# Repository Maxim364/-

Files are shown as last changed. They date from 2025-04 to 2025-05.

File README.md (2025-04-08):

# Электронно-механические часы на ПЛИС

## Описание проекта

Данный проект представляет собой курсовую работу, посвящённую разработке электронно-механических часов на базе программируемой логической интегральной схемы (ПЛИС) с использованием встроенного процессора (HPS). В рамках проекта реализована система, получающая текущее время из операционной системы Linux, работающей на HPS, и передающая его в ПЛИС для аппаратного отображения. Также предусмотрено управление подсветкой часов с помощью Python-программы.

Проект объединяет аппаратную и программную части, а также 3D-моделирование.

## Состав репозитория

Репозиторий содержит следующие основные компоненты:

### 1. **Проект Quartus**
Каталог `quartus_project/` содержит файлы проекта Quartus Prime, включая:

- HDL-файлы, реализующие логику отображения времени;
- Проект Qsys с настройкой взаимодействия между HPS и FPGA;
- Конфигурационные файлы (`.qsf`, `.qpf`, `.sdc`) проекта Quartus.

### 2. **Программа для HPS**
Каталог `hps_program/` содержит C-программу, выполняемую на процессоре HPS:

- Получение текущего времени из Linux и передача его в FPGA посредством C-программы;
- Makefile для сборки программы под ARM-платформу.
- Скомпилированная C-программа.

### 3. **3D-модель часов**
Каталог `models/` включает файлы для реализации 3D-модели часов:

- 3D-модели каждого элемента часов.
- Сборка модели.
- STL файлы для печати на 3D-принтере.

### 4. **Скрипт управления подсветкой**
Каталог `python_tools/` содержит Python-скрипт, управляющий подсветкой устройства:

- `backlight_control.py` — позволяет переключать режимы подсветки;

### 5. **Документация**
Каталог `doc/` содержит материалы курсовой работы:

- Отчет;
- Руководство разработчика;
- Руководство пользователя.

### 6. **Образ Linux**
Каталог `linux_image/` содержит необходимые файлы для запуска Linux на HPS:

- Предсобранный образ Linux (`Image`);
- Инструкции по прошивке на SD-карту;

## Назначение проекта

Проект направлен на интеграцию программируемой логики с системой на базе Linux, развитие навыков работы с ПЛИС и системным программированием, а также демонстрацию взаимодействия аппаратных и программных средств в рамках одной функциональной системы.

---

**Авторы:** *Батаев Максим, Леснов Илья*  
**Проект выполнен в рамках курсовой работы по дисциплине "Алгоритмизация и программирование"*

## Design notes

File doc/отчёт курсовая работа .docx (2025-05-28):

ФЕДЕРАЛЬНОЕ ГОСУДАРСТВЕННОЕ АВТОНОМНОЕ ОБРАЗОВАТЕЛЬНОЕ УЧРЕЖДЕНИЕ ВЫСШЕГО ОБРАЗОВАНИЯ

«НАЦИОНАЛЬНЫЙ ИССЛЕДОВАТЕЛЬСКИЙ УНИВЕРСИТЕТ

«ВЫСШАЯ ШКОЛА ЭКОНОМИКИ»

###### МОСКОВСКИЙ ИНСТИТУТ ЭЛЕКТРОНИКИ И МАТЕМАТИКИ

###### им. А.Н. ТИХОНОВА

Леснов Илья Андреевич, группа БИВ248

Батаев Максим Алексеевич, группа БИВ248

ЭЛЕКТРОННО-МЕХАНИЧЕСКИЕ ЧАСЫ НА ПЛИС

Курсовая работа

по направлению 09.03.01 Информатика и вычислительная техника

студентов образовательной программы бакалавриата
«Информатика и вычислительная техника»

Студент ___________________ _________________

подпись И.О. Фамилия

Студент ___________________ _________________

подпись И.О. Фамилия

Рецензент ученая степень, звание (при наличии) ___________________ И.О. Фамилия | Руководитель ученая степень, звание (при наличии) ____________________ И.О. Фамилия Консультант ученая степень, звание (при наличии) ____________________ И.О. Фамилия

ЗАДАНИЕ НА КР

ФЕДЕРАЛЬНОЕ ГОСУДАРСТВЕННОЕ АВТОНОМНОЕ ОБРАЗОВАТЕЛЬНОЕ УЧРЕЖДЕНИЕ ВЫСШЕГО ОБРАЗОВАНИЯ

«НАЦИОНАЛЬНЫЙ ИССЛЕДОВАТЕЛЬСКИЙ УНИВЕРСИТЕТ

«ВЫСШАЯ ШКОЛА ЭКОНОМИКИ»

###### МОСКОВСКИЙ ИНСТИТУТ ЭЛЕКТРОНИКИ И МАТЕМАТИКИ

ЗАДАНИЕ

на курсовую работу бакалавра

студенту группы БИВ248 Леснову Илье Андреевичу

1. Тема работы

Электронно-механические часы на ПЛИС

Electronic-mechanical clock on FPGA

2. Требования к работе

Разработать Электронно-Механические часы на ПЛИС. Часы должны брать актуальное время из сети Интернет и выводить его с помощью семисегментных «дисплеев» на сервомоторах. Время должно обновляться при движении перед часами в течение трёх минут.

  2.1. Требование к составу технических средств:

Часы реализуются на плате DE1-Soc, также при создании часов должны быть использованы Servo Motor Kit для управления 28-ью сервомоторами. Часы должны быть оснащены датчиком движения. Для установки Linux на плату должны быть использованы кабель Micro-USB (для разъёма UART-USB), карта памяти microSD (8 ГБ или больше) и устройство для чтения карт памяти microSD.

  2.2. Требования к программной части:

Для работы часов должна быть разработана программа на языке Verilog в среде разработки Quartus (Quartus Prime 17.1) Lite Edition. Также для получения актуальных данных времени из сети интернет на плату должна быть загружена операционная система Linux, разработана программа на языке C в среде разработки Visual Studio.

3. Содержание работы

  3.1. Поиск и анализ аналогов.
  3.2. Разработка программной части часов.
    3.2.1. Загрузка Linux на плату.
    3.2.2. Разработка программы для работы часов.
    3.2.3. Загрузка программ на плату.
  3.3. Разработка технической части часов.
    3.3.1. Разработка корпуса и печать 3Д модели сегментов.
    3.3.2. Сборка часов.
  3.4. Тестирование часов.
4. Требование к программной документации
  4.1. Отчет;
  4.2. Описание алгоритма решения задачи;
  4.3. Описание кода программы;
  4.4. Описание тестирования.
5. Сроки выполнения этапов работы

Первый вариант КР предоставляется студентом в срок до

«28» марта 2025г.

Итоговый вариант КР предоставляется студентом в срок до

«31» мая 2025г.

Задание выдано | «___» ___________ 202_г. | ____________ Е. В. Лежнев подпись руководителя
Задание принято к исполнению | «___» ___________ 202_г. | ____________ И. А. Леснов подпись студента

ФЕДЕРАЛЬНОЕ ГОСУДАРСТВЕННОЕ АВТОНОМНОЕ ОБРАЗОВАТЕЛЬНОЕ УЧРЕЖДЕНИЕ ВЫСШЕГО ОБРАЗОВАНИЯ

«НАЦИОНАЛЬНЫЙ ИССЛЕДОВАТЕЛЬСКИЙ УНИВЕРСИТЕТ

«ВЫСШАЯ ШКОЛА ЭКОНОМИКИ»

###### МОСКОВСКИЙ ИНСТИТУТ ЭЛЕКТРОНИКИ И МАТЕМАТИКИ

График выполнения

курсовой работы бакалавра

студента группы БИВ248 Леснова Ильи Андреевича

Тема работы

Электронно-механические часы на ПЛИС

Electronic-mechanical clock on FPGA

Дата согласования первого варианта КР | «___» __________ 202_г. | ____________ Е. В. Лежнев подпись руководителя
Дата согласования итогового варианта КР | «___» __________ 202_г. | ____________ Е. В. Лежнев подпись руководителя

ФЕДЕРАЛЬНОЕ ГОСУДАРСТВЕННОЕ АВТОНОМНОЕ ОБРАЗОВАТЕЛЬНОЕ УЧРЕЖДЕНИЕ ВЫСШЕГО ОБРАЗОВАНИЯ

«НАЦИОНАЛЬНЫЙ ИССЛЕДОВАТЕЛЬСКИЙ УНИВЕРСИТЕТ

«ВЫСШАЯ ШКОЛА ЭКОНОМИКИ»

###### МОСКОВСКИЙ ИНСТИТУТ ЭЛЕКТРОНИКИ И МАТЕМАТИКИ

ЗАДАНИЕ

на курсовую работу бакалавра

студенту группы БИВ248 Батаеву Максиму Алексеевичу

1. Тема работы

Электронно-механические часы на ПЛИС

Electronic-mechanical clock on FPGA

2. Требования к работе

Разработать Электронно-Механические часы на ПЛИС. Часы должны брать актуальное время из сети Интернет и выводить его с помощью семисегментных «дисплеев» на сервомоторах.

  2.1. Требование к составу технических средств:

Часы реализуются на плате DE1-Soc, также при создании часов должны быть использованы Servo Motor Kit, для управления 28-ью сервомоторами, сегменты часов должны быть реализованы с помощью аддитивных технологий (распечатаны на 3Д-принтере), делать весь корпус часов на 3Д-принтере нецелесообразно поэтому для этого могут быть использованы другие материалы и способы, часы должны быть оснащены датчиком движения.

  2.2. Требования к программной части:

Для работы часов должны быть разработана программа на языке Verilog в среде разработки Quartus (Quartus Prime 17.1) Lite Edition, также для получения актуальных данных времени из сети интернет на плату должна быть загружена операционная система Linux. Сегменты часов должны быть разработаны в САПР для 3Д-моделирования – Компас 3D.

3. Содержание работы

  3.1. Поиск и анализ аналогов.
  3.2. Разработка программной части часов.
    3.2.1. Загрузка Linux на плату.
    3.2.2. Разработка программы для работы часов.
    3.2.3. Загрузка программ на плату.
  3.3. Разработка технической части часов.
    3.3.1. Разработка корпуса и печать 3Д модели сегментов.
    3.3.2. Сборка часов.
  3.4. Тестирование часов.
4. Требование к программной документации
  4.1. Отчет;
  4.2. Описание алгоритма решения задачи;
  4.3. Описание кода программы;
  4.4. Описание тестирования.
5. Сроки выполнения этапов работы

Первый вариант КР предоставляется студентом в срок до

«28» марта 2025г.

Итоговый вариант КР предоставляется студентом в срок до

«31» мая 2025г.

Задание выдано | «___» ___________ 202_г. | ____________ Е. В. Лежнев подпись руководителя
Задание принято к исполнению | «___» ___________ 202_г. | ____________ М. А. Батаев подпись студента

ФЕДЕРАЛЬНОЕ ГОСУДАРСТВЕННОЕ АВТОНОМНОЕ ОБРАЗОВАТЕЛЬНОЕ УЧРЕЖДЕНИЕ ВЫСШЕГО ОБРАЗОВАНИЯ

«НАЦИОНАЛЬНЫЙ ИССЛЕДОВАТЕЛЬСКИЙ УНИВЕРСИТЕТ

«ВЫСШАЯ ШКОЛА ЭКОНОМИКИ»

###### МОСКОВСКИЙ ИНСТИТУТ ЭЛЕКТРОНИКИ И МАТЕМАТИКИ

График выполнения

курсовой работы бакалавра

студента группы БИВ248 Батаева Максима Алексеевича

Тема работы

Электронно-механические часы на ПЛИС

Electronic-mechanical clock on FPGA

Дата согласования первого варианта КР | «___» __________ 202_г. | ____________ Е. В. Лежнев подпись руководителя
Дата согласования итогового варианта КР | «___» __________ 202_г. | ____________ Е. В. Лежнев подпись руководителя

АННОТАЦИЯ

Объект разработки: электронно-механические часы на базе ПЛИС DE1-SoC.

Цель работы: разработка и создание электронно-механических часов с использованием ПЛИС DE1-SoC, сервомоторов и семисегментных индикаторов для отображения времени, полученного из сети Интернет через HPS в Linux.

Краткое описание полученных результатов: в ходе работы были разработаны и собраны электронно-механические часы, которые отображают время на четырёх семисегментных индикаторах с помощью сервомоторов и пластиковых лопастей. Также на часах установлен датчик движения, который активирует отображение времени при обнаружении движения, добавлена декоративная LED-подсветка. Итоговая структурированная версия работы представлена на Github: https://github.com/Maxim364/-

Рекомендации по использованию результатов: разработанные часы могут быть использованы в качестве демонстрационного проекта для изучения принципов работы с ПЛИС, сервомоторами и датчиками движения. Результаты работы могут быть полезны для студентов, изучающих электронику и программирование.

Направления дальнейших разработок: улучшение дизайна часов, добавление дополнительных функций (например, отображения даты, будильника), оптимизация программного обеспечения для более точного отображения времени.

Объём работы: 26 стр.

Количество иллюстраций: 12

Количество таблиц: 1

Количество использованных источников: 7

ABSTRACT

Development object: electronic-mechanical watch based on FPGA DE1-SoC.

The aim of the work: to develop and create electronic-mechanical watches using FPGA DE1-SoC, servo motors and seven-segment displays to display the time obtained from the Internet via HPS in Linux.

Brief description of the results obtained: during the work, electronic-mechanical watches were developed and assembled, which display the time on four seven-segment displays using servo motors and plastic blades. The watch also has a motion sensor that activates the time display when motion is detected, decorative LED lighting added. The final structured version of the work is presented on Github: https://github.com/Maxim364/-

Recommendations for the use of the results: the developed watch can be used as a demonstration project to study the principles of working with FPGA, servo motors and motion sensors. The results of the work can be useful for students studying electronics and programming.

Directions for further development: improving the design of the watch, adding additional functions (for example, displaying the date, alarm clock), optimizing the software for more accurate time display.

Volume of work: 26 p.

Number of illustrations: 12

Number of tables: 1

Number of sources used: 7

СОДЕРЖАНИЕ

# 1 Введение

УЛ САПР в МИЭМ специализируется на разработке различных проектов на базе ПЛИС. Результат данной курсовой работы – электронно-механические часы на ПЛИС – несёт в себе цель стать демонстрационным макетом для различных мероприятий МИЭМ, на примере которого можно будет познакомить посетителей с ПЛИС, рассказать об их основном функционале, принципах работы и тонкостях программирования.

Электронно-механические часы на ПЛИС представляют собой устройство, сочетающее в себе программируемую логику и механические исполнительные механизмы.

В основе курсовой работы лежит проект [1] электронно-механических часов на Arduino Nano, взаимодействующая с двумя платами из набора Servo Motor Kit для управления сервомоторами, которые, в свою очередь, управляют механическими сегментами, составляющими цифры для отображения текущего времени. Часы также оснащены датчиком движения, что позволяет отображать время не всегда, а только при необходимости, чтобы избежать постоянного шума от работы механизмов. Наша же задача состоит в том, чтобы реализовать схожий функционал, используя ПЛИС Terasik DE1-SoC.

Также был найден проект [2], реализующий функционал часов на другой плате. В нём описывается разработка на ПЛИС Lattice LC4064v. Однако время отображается с помощью светодиодных семисегментных индикаторов, а отсчёт происходит с помощью 15-битного двоичного счётчика с использованием генератора тактового сигнала 50 МГц. В другом проекте [3] описан процесс создания часов на ПЛИС Terasic DE0-Nano. Проект демонстрирует возможности синтеза цифровых схем для работы с таймингами также выводя время на светодиодных семисегментных индикаторах с тремя двоичными счётчиками, реализованными на логических элементах платы.

В текущей работе вычисление времени с помощью счётчиков будет заменено на вывод текущего времени, полученного из сети интернет. Микросхемы оснащены адаптивными логическими модулями и блоками оперативной памяти и цифровой обработки сигналов переменной точности, а также порт для кабеля Ethernet, что позволит использовать ОС Linux для программирования на языке C для получения текущего времени из сети интернет. Пример проекта [4], использующего возможности ПЛИС для запуска Linux: Запуск Linux на MIPSfpga и ПЛИС Altera – рассмотрен процесс сборки и запуска Linux на FPGA-платформе.

Рассмотренные проекты демонстрируют различные подходы к созданию электронно-механических часов на ПЛИС. Особый интерес представляет возможность интеграции ПЛИС с сервоприводами, что открывает перспективы для реализации сложных механизмов индикации времени. В рамках данной курсовой работы функционал предыдущих проектов будет объединён и расширен, а также будет приведён к цельному виду. Разработанные материалы будут храниться в репозитории Github [5].

# 2 Теоретическое введение

ПЛИС (Программируемая логическая интегральная схема) [6] – интегральная микросхема, используемая для создания конфигурируемых цифровых электронных схем, логика которых не определяется при изготовлении, а задаётся с помощью программирования.

Сервопривод (сервомотор) [7] – механический привод с автоматической коррекцией состояния через внутреннюю отрицательную обратную связь, в соответствии с параметрами, заданными извне.

Архитектура ARM (Advanced RISC Machine) – система команд и семейство описаний и готовых топологий 32-битных и 64-битных микропроцессорных/микроконтроллерных ядер, разрабатываемых компанией ARM Limited.

HPS – это термин, используемый Intel-Altera для определения процессорного блока, который в нашем случае представляет собой процессор ARM A9 (который может быть другим ARM в зависимости от семейства FPGA).

Шина – набор проводников (и схем их управления) для передачи информации и/или питания между функциональными электронными блоками.

IP-блоки – готовые блоки для проектирования микросхем.

Verilog, Verilog HDL (Verilog Hardware Description Language) – это язык описания аппаратуры, используемый для описания и моделирования электронных систем.

Широтно-импульсная модуляция (ШИМ, англ. pulse-width modulation (PWM)) – процесс управления мощностью методом пульсирующего включения и выключения потребителя энергии.

Интерфейс ввода/вывода общего назначения (англ. general-purpose input/output, GPIO) – интерфейс для связи между компонентами компьютерной системы.

# 3 Аппаратное обеспечение

Плата DE1-SoC. Плата DE1-SoC оснащена FPGA Cyclone V, двумя ядрами ARM (HPS), ОЗУ DDR3, ПЗУ. В нашем проекте используются GPIO-разъёмы платы для подключения внешних устройств: сервоприводов, светодиодной ленты и датчика движения. Питание платы обеспечивается от внешнего адаптера 12 В, платы Servo-Motor-Kit (SMK) также требуют питания 12 В (минимум 5 А для работы с нагрузкой сервомоторов).

## 3.1 Подключение компонентов.

По разработанной схеме подключения сервомоторы и сенсоры соединяются с GPIO DE1-SoC шлейфами следующим образом:

- DE1-SoC GPIO0[0..13] → сервоприводы часов
- DE1-SoC GPIO1[0..13] → сервоприводы минут
- DE1-SoC GPIO0[20..22] → LED-подсветка
- DE1-SoC GPIO0[23] → датчик движения
- DE1-SoC GPIO1[22, 23] → разделительные светодиоды

## 3.2 Сервоприводы.

Каждый сервомотор имеет два основных положения: 0° и 90°, обеспечивая поворот сегмента часов на нужный угол. Напряжение питания моторов подаётся через платы Servo-Motor-Kit, а сигналы управления формируются FPGA и передаются на SMK по шлейфам GPIO.

## 3.3 Семисегментные индикаторы.

Для отображения цифрового времени используются два набора 7-сегментных индикаторов («часы» и «минуты»). Модули FPGA (seven_segment.v) кодируют цифры из ARM в сигналы, управляющие сегментами. Индикаторы запитываются от платы и подключены к соответствующим выходам FPGA. Они служат ориентиром для отладки работы основных часов и выявления неисправных сервомоторов.

## 3.4 Светодиодная лента.

RGB-подсветка подключена к трём GPIO выходам FPGA (GPIO0[20..22]) и управляется через чат Zulip, задавая цвет свечения. Команды от ARM к ленте передаются через шину Avalon Lite и обрабатываются модулем color.v. Так демонстрируется экосистема МИЭМ, в которой студенты могут использовать сервисы института для реализации разнообразного функционала.

## 3.5 Датчик движения.

К порту GPIO0[23] подключён датчик движения. Модуль motion_detector.v считывает его состояние и формирует команду на «пробуждение» часов (активацию перемещения сегментов в нужное положение). Это позволяет часам реагировать на появление человека в зоне обзора. После этого часы остаются активными ещё 2 минуты, затем перестают менять время до следующего сигнала о наличии движения. Сделано это для того, чтобы избежать постоянного шума от поворота сегментов и лишних затрат электроэнергии, когда часы не используются.

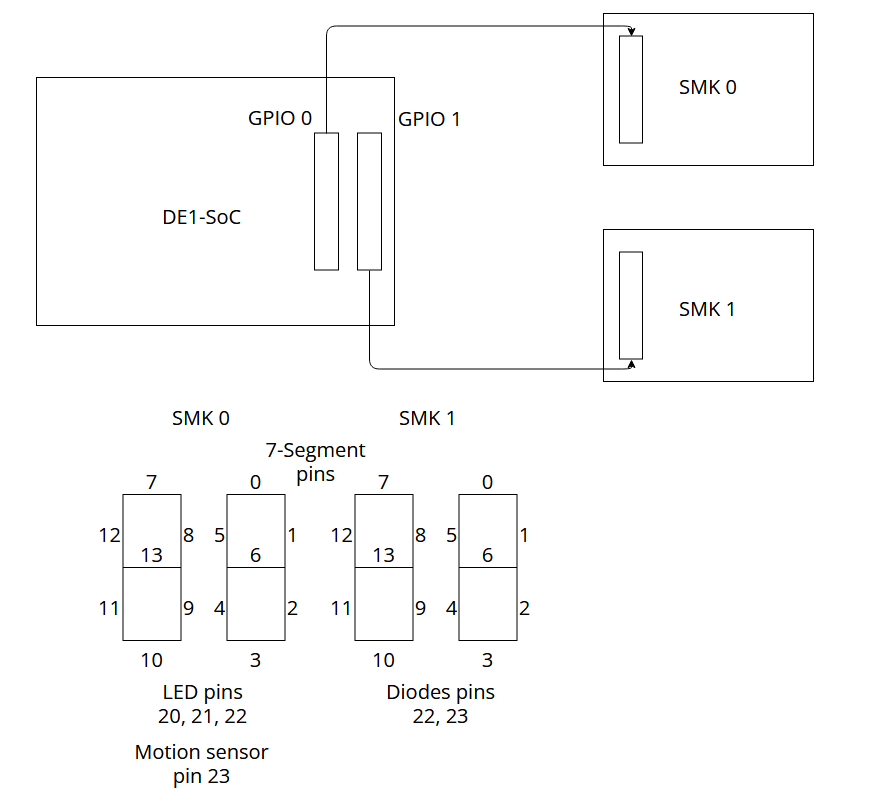
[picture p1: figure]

Рисунок 1. Схема подключения сервоприводов, диодов и датчика движения

# 4 Проектирование системы в Quartus Prime и Platform Designer

Проект выполнен в среде Quartus Prime 17.1 с использованием Platform Designer (Qsys) версии 17.1.1. В Platform Designer создаётся аппаратная платформа на основе Cyclone V SoC: объединяются ядро HPS, необходимые периферийные IP-блоки (PIO, On-chip Memory, JTAG UART, System ID и т.д.) и настраиваются адреса и связи.

## 4.1 Создание Qsys-системы.

Новый Qsys-проект soc_system.qsys содержит HPS-компонент «hps_0» и несколько модулей PIO (Parallel Input/Output) для управления внешними устройствами. Компоненты PIO добавляются из библиотеки Qsys, настраиваются ширина порта данных и направление «Output» для управления лентой, моторами и индикаторами. Каждый PIO подключён к шине AXI h2f_lw (light-weight AXI Master HPS) и получает выделенный диапазон адресов. Например, был настроен PIO под названием pio_led, который управляет LED-подсветкой, с базовым адресом 0x0000_0000. Аналогично добавляются и настраиваются PIO под pio_motors для управления сервомоторами и pio_sensors для управления датчиком движения, при этом каждому назначается уникальный базовый адрес. Полный перечень блоков и их настроек подключения находится в Таблице 1.

Таблица 1. Связи IP-блоков

IP-блок | Имя интерфейса | Тип интерфейса | Базовый адрес | Конечный адрес
HPS | hps_0 | AXI Master | 0x00000000 | 0xffffffff
PIO (LED) | pio_led | AXI Lite Slave | 0x00000000 | 0x0000000f
JTAG to Avalon Master Bridge | hps_only_master | AXI Lite Slave | - | -
System ID | sysid_qsys | AMM Slave | 0x00010000 | 0x00010007
Onchip-memory | onchip_memory2_0 | AMM Slave | 0x00000000 | 0x0000ffff
JTAG UART | jtag_uart | AMM Slave | 0x00020000 | 0x00020007
JTAG to Avalon Master Bridge | fpga_only_master | AMM Master | - | -
Clock source | clk_0 | PIO | - | -

## 4.2 Коммутация интерфейсов.

После добавления компонентов они соединяются в графическом редакторе Qsys. Основные интерфейсные связи: AXI-порты HPS связаны с PIO и on-chip memory (см. Рисунок 2). Также задействован JTAG UART для отладки и System ID для идентификации сборки. На этапе генерации Qsys создаётся HDL-код (Verilog/VHDL), который затем включается в проект Quartus (файлы *.qip и *.v).

## 4.3 Карта адресов.

Platform Designer генерирует карту памяти для FPGA-компонентов. Например, в проекте HPS занимает весь 32-битный адресный диапазон (0x0000_0000–0xFFFFFFFF), PIO для LED – адреса 0x0000_0000–0x0000_000F (ширина 10 бит), on-chip memory – 0x0000_0000–0x0000_FFFF, JTAG UART – 0x0002_0000–0x0002_0007 и др. (см. Таблица 1). Эта карта адресов используется ARM-программой для записи и чтения данных в FPGA.

После настройки Qsys выполняется генерация HDL. Сгенерированные файлы .qip, .vhd/.v добавляются в проект Quartus. Затем указывается Qsys-топ (ghrd_top.v) как корневой Entity и запускается компиляцию FPGA. В результате получается образ ПЛИС (.sof) для загрузки в FPGA.

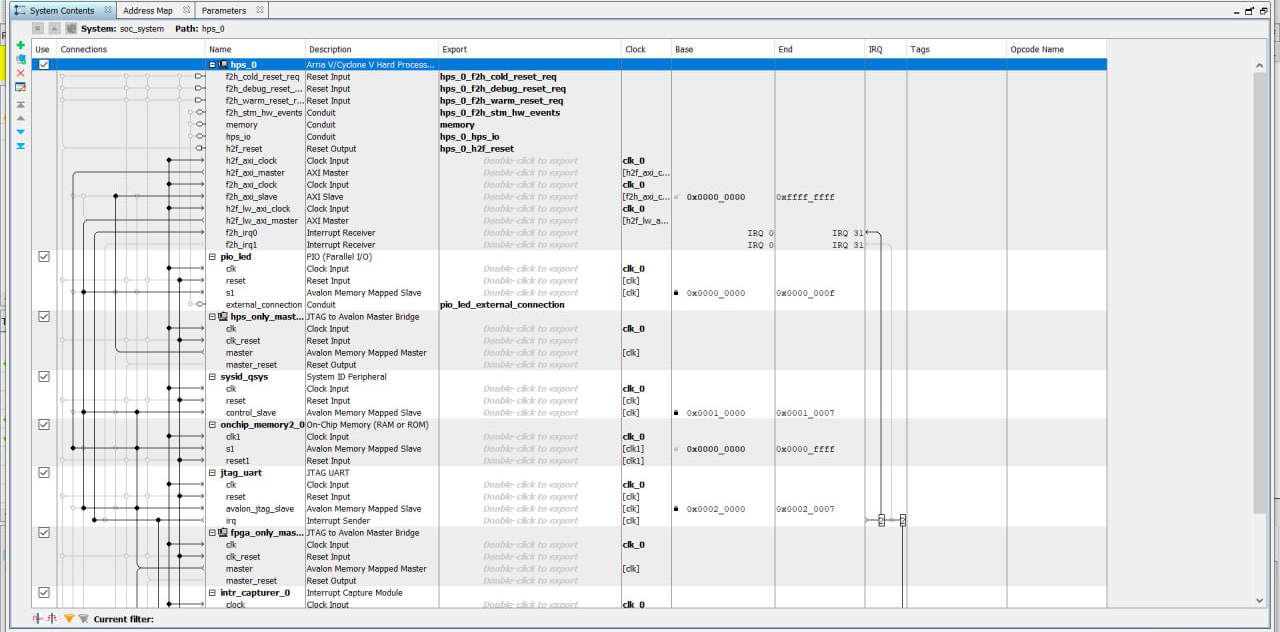
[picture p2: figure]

Рисунок 2.1. Блок-схема системы в Platform Designer (Qsys)

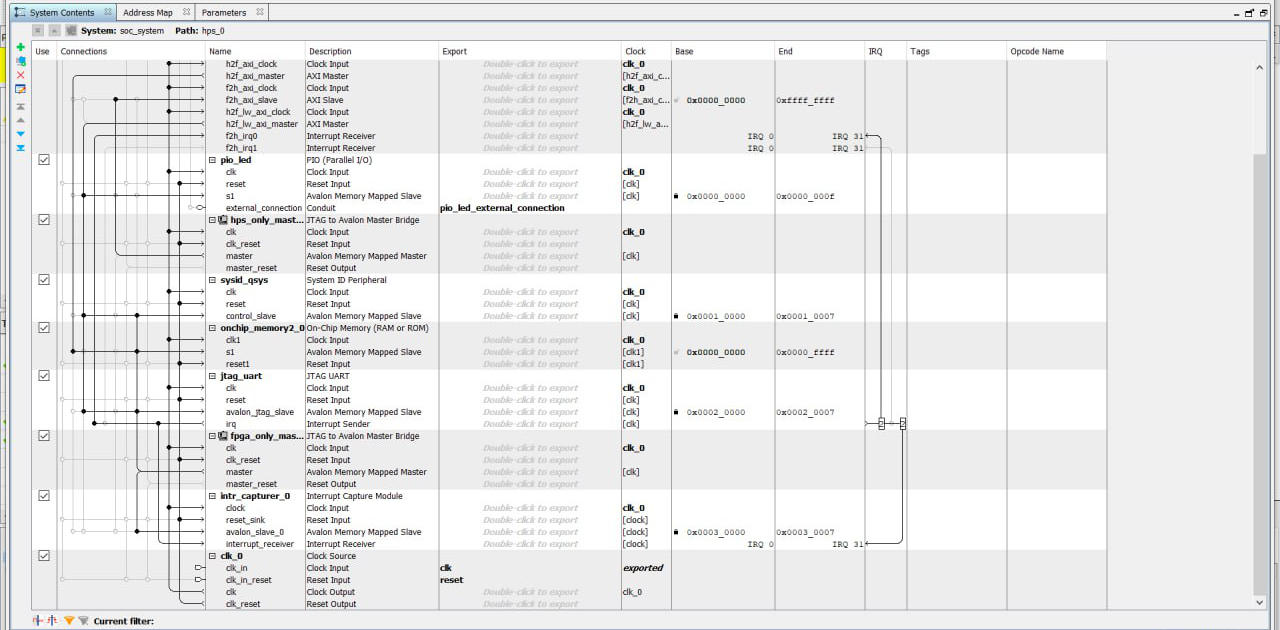
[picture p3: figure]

Рисунок 2.2. Блок-схема системы в Platform Designer (Qsys)

# 5 3D-модель и корпус (Kompas-3D)

Для механической части часов разработана 3D-модель корпуса, креплений и сегментов в программном обеспечении Компас-3D. В исходном репозитории проекта приведены CAD-файлы 3D-моделей: четыре части корпуса, ножка, крепления сервомоторов, подставки, сегменты цифр.

Смоделированные детали экспортированы в формат STL и подготовлены к 3D-печати (слой 0.2 мм, заполнение 20 %, PLA-пластик). Это позволило изготовить корпус и подвижные элементы, интегрированные с сервоприводами. Конструкция 3D-модели обеспечивает точное позиционирование сервомоторов и закреплённых на них сегментов для корректного отображения времени.

В ходе работы над проектом данная 3D-модель улучшалась вследствие выявленных недостатков. Так, были укреплены соединения между частями корпуса из-за немалого веса плат DE1-SoC и SMK, а также сервомоторов с сегментами.

При сборке данного макета были выявлены некоторые проблемы с 3D-моделью проекта. Некоторые сегменты мешали друг-другу совершать полноценные движения, так как при разработке их 3D-моделей не учлись шероховатости напечатанной поверхности, а также неточности, допускаемые при ручной сборке часов. Чтобы избежать этих проблем были улучшены детали, служащие для крепления сегментов к сервомоторам, а также выступающие элементы корпуса, служащие для закрепления самих сервомоторов.

Всего в сборке 99 элементов (Рис. 3): 3 габаритных экземпляра плат (1 DE1-SoC и 2 SMK), 28 сервомоторов, 28 креплений сегментов, 28 сегментов (8 Сегментов 1, 8 Сегментов 2, 8 Сегментов 4, 4 Сегмента 3), 4 части корпуса, 6 креплений корпуса (Крепление 1, Крепление 2, Крепление 3, 3 Крепления 4), 2 подставки корпуса. Из них 68 напечатаны на 3D-принтере.

Для объединения элементов в сборку были использованы сопряжения. Элемент Крепление сегмента крепится к элементу Сегмент с помощью сопряжений «Совпадение»: верхняя плоскость Крепления сегмента крепится к плоскости выемки Сегмента, и «Расстояние»: две боковые перпендикулярные плоскости Сегмента устанавливаются на расстоянии 0 от соответствующих плоскостей Крепления сегмента. Сервомоторы устанавливаются с помощью сопряжений «Совпадение», применяемых между нижней плоскостью Сервомотора и Верхней плоскости Корпуса, а также между вертикальными плоскостями специальных выпуклых элементов Корпуса и Сервомоторов. Сервомоторы имеют специальные насадки, закрепляющиеся с помощью инструментов «Соосность» и «Совпадение». Сегменты с Креплениями крепятся к Сервомоторам с помощью сопряжения «Совпадение» между плоскостями выемки на Креплении и насадок. При желании можно добавить сопряжение «Расстояние» или «Под углом», ограничивающее движение насадки и Сегмента с Креплением до плоскости Корпуса. Подставки корпуса крепятся с помощью сопряжения «Совпадение» между прилегающими плоскостями и «Соосность» между отверстиями на Корпусе и Подставках. Аналогично крепятся Крепления корпуса. Части корпуса крепятся с помощью сопряжения «Совпадение» между прилегающими плоскостями и креплениями.

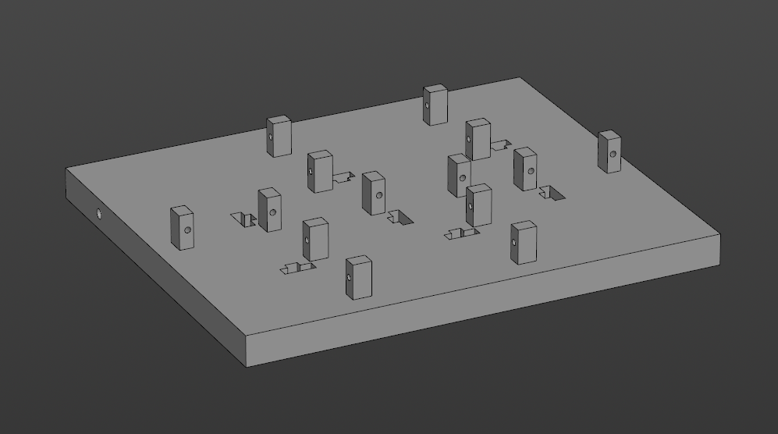
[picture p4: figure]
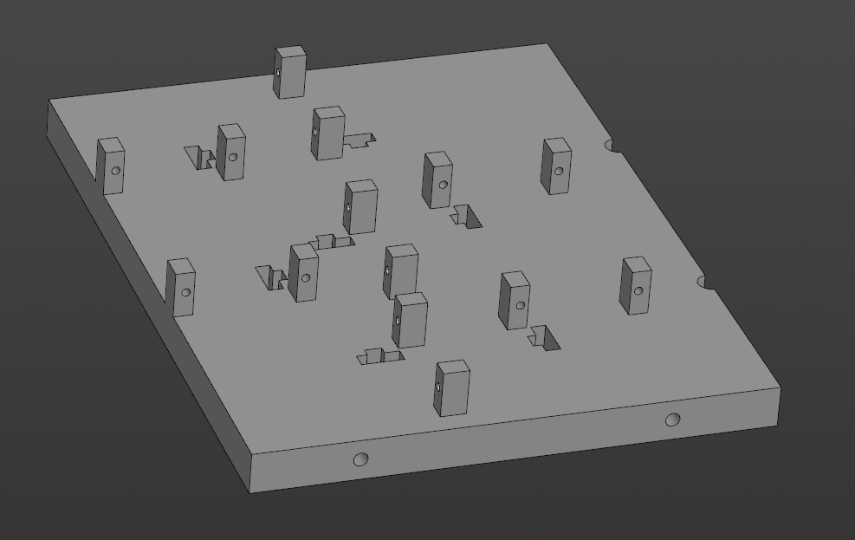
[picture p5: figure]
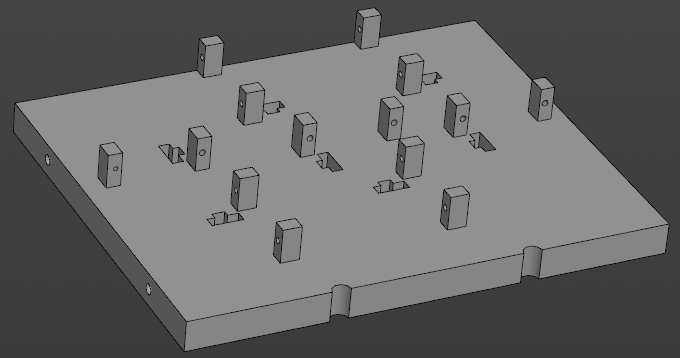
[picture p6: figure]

Корпус часть 1 Корпус часть 2 Корпус часть 3

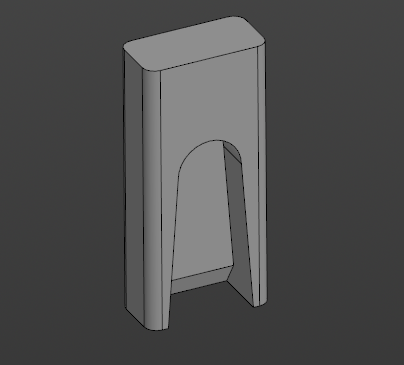
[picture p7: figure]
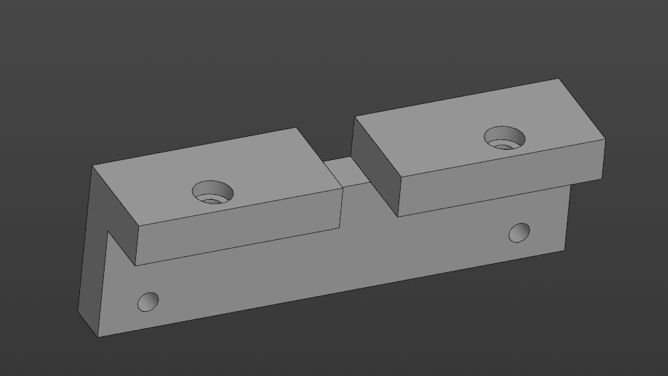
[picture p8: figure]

Корпус часть 4 Крепление сегмента Крепление корпуса 1

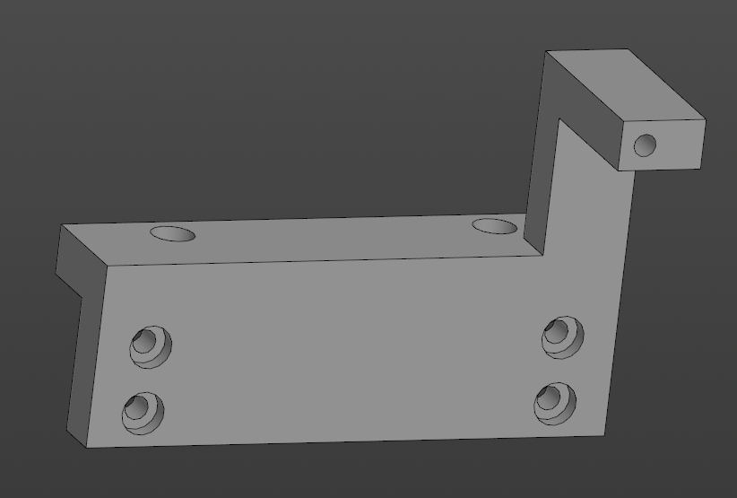
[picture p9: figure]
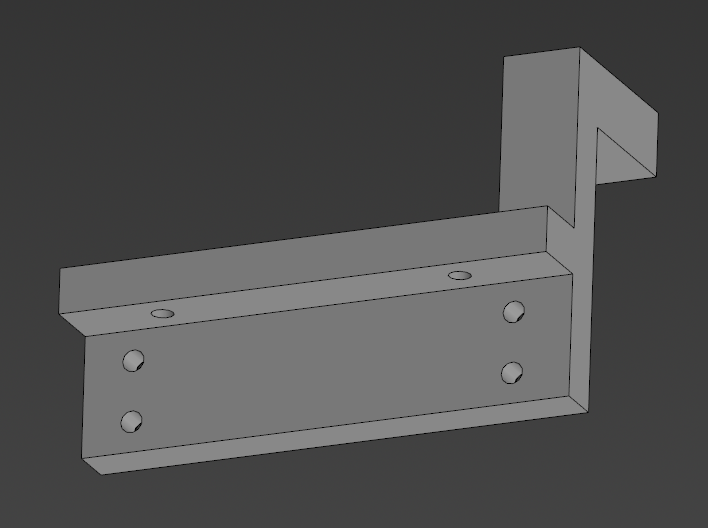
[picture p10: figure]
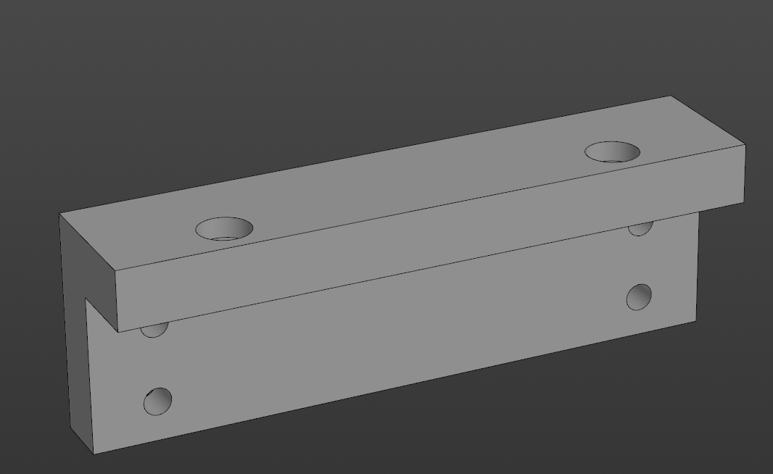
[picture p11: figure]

Крепление корпуса 2 Крепление корпуса 3 Крепление корпуса 4

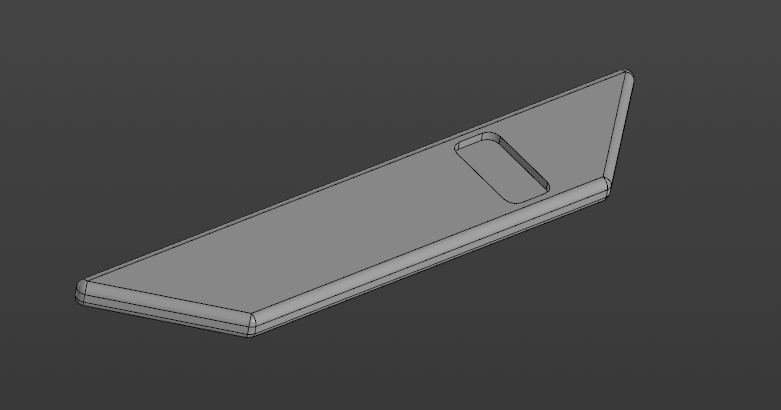
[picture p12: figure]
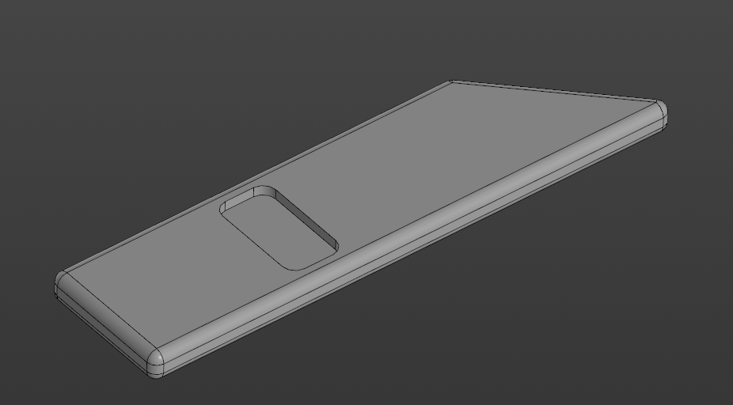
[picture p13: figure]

Подставка корпуса Сегмент 1 Сегмент 2

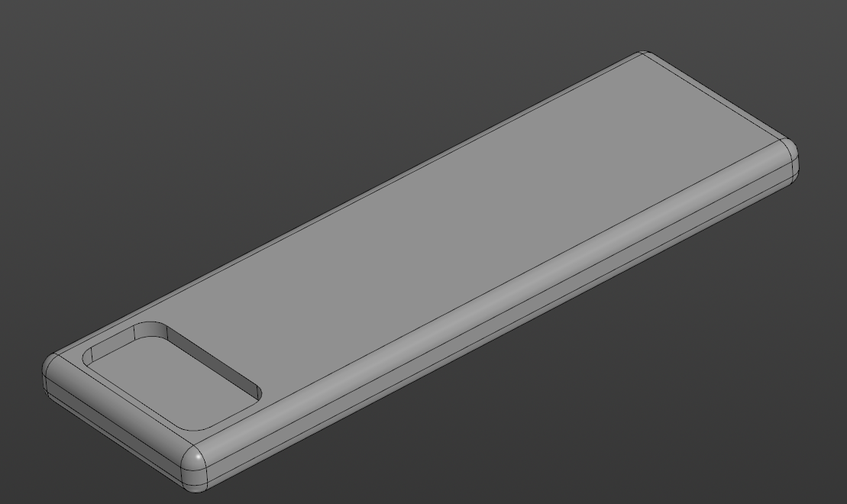
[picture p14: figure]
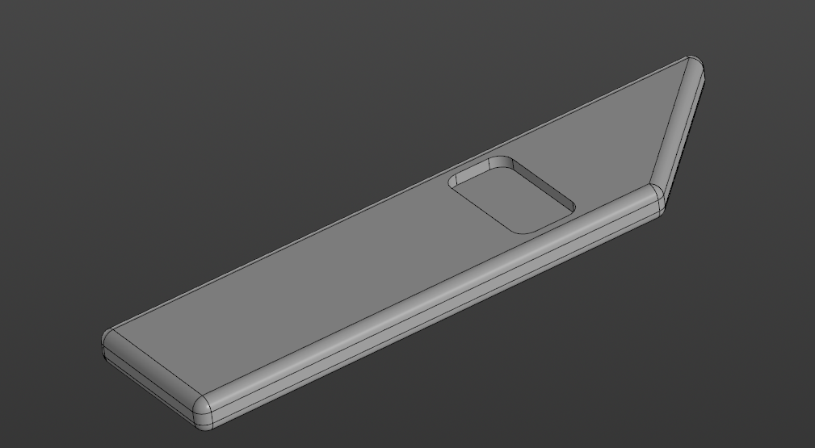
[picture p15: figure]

Сегмент 3 Сегмент 4

Рисунок 3. Печатные элементы сборки

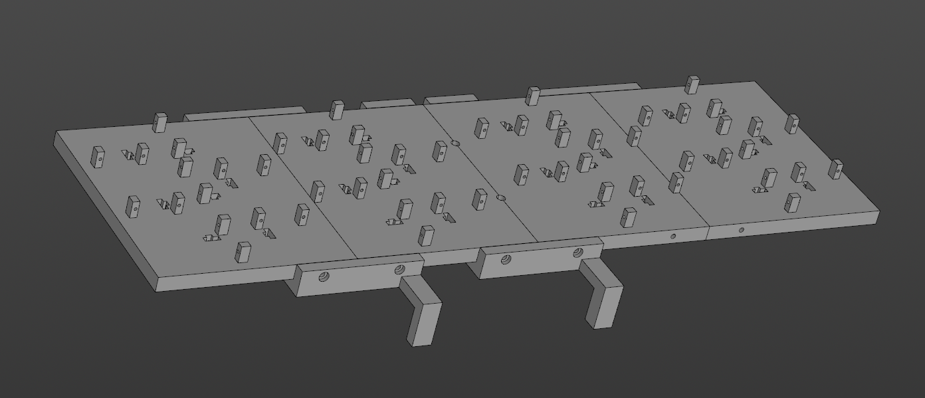
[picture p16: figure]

‍‍‍‍

Рисунок 4. 3D-модель корпуса часов.

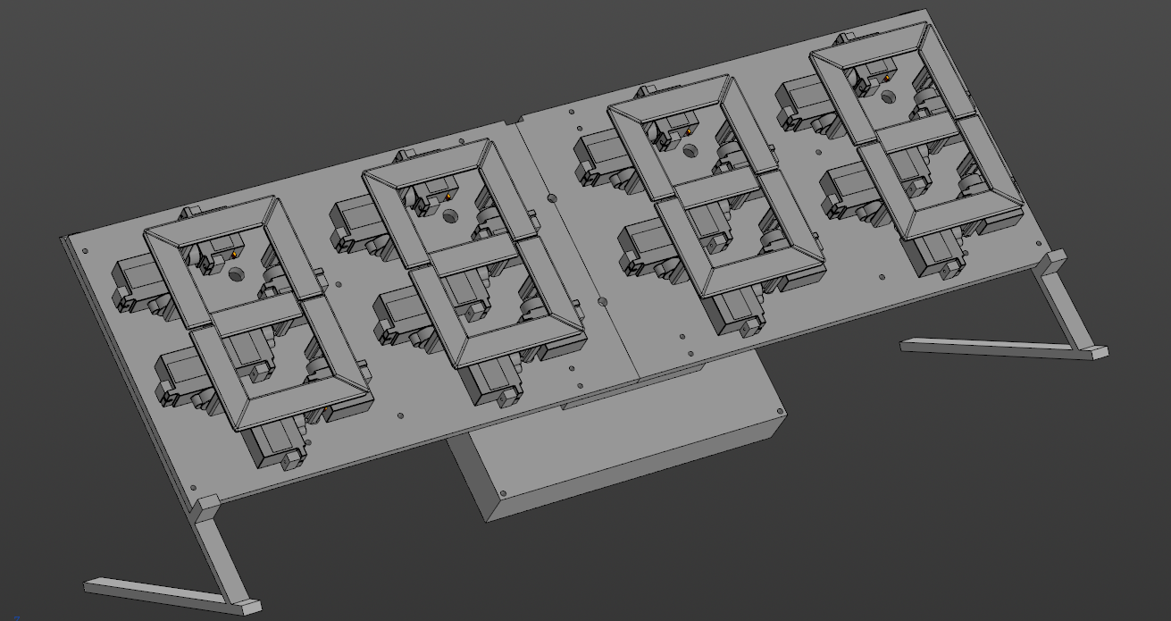
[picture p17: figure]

Рисунок 5. Старая модель.

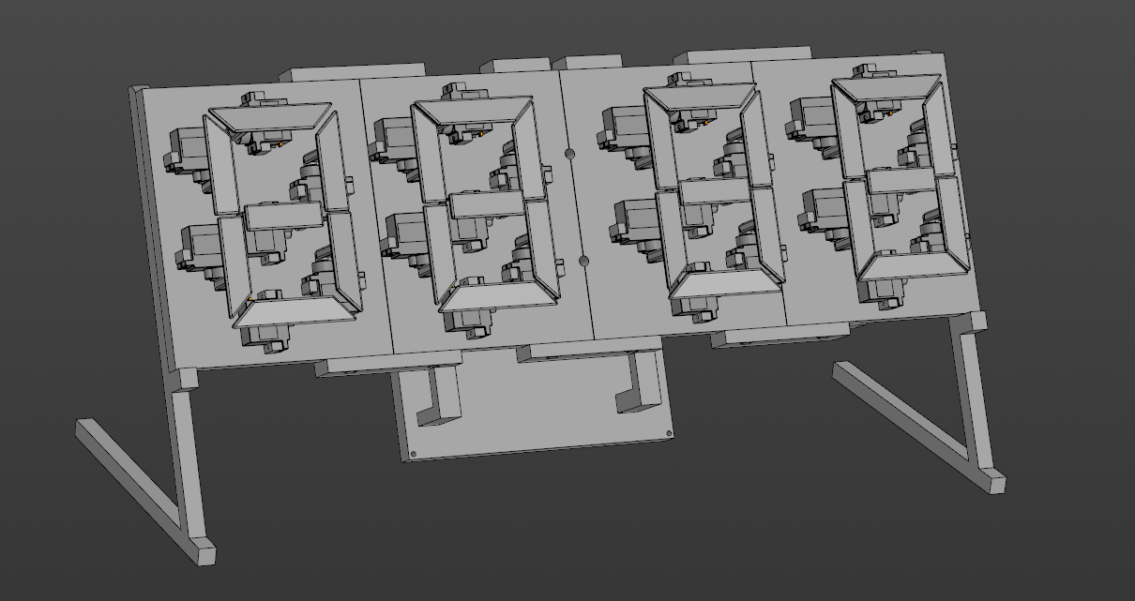
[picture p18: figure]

Рисунок 6. Итоговая сборка

# 6 Разработка FPGA (Verilog)

В FPGA-части проекта разработано несколько модулей на языке Verilog, выполняющих логику часов и связь с внешними компонентами. Основные модули проекта:

## 6.1 Модуль ghrd_top.v.

Верхнеуровневый модуль системы (top-level). Он отвечает за приём 32-битного слова из программы на Си (HPS) и распределение полученных данных между остальными блоками FPGA. В нём объявляются все входы и выходы (часы, сброс, GPIO, сигналы сегментов и т.д.) и устанавливаются связи с другими модулями (ntp_clock, color, seven_segment и др.). Процесс верификации начинается с компиляции ghrd_top.v после генерации Qsys.

## 6.2 Модуль ntp_clock.v.

Ключевой модуль управления. Он содержит основную логику часов: разбивает 32-битный пакет из HPS на составляющие (цвет подсветки, цифры часов и минут), преобразует эти цифры в сигналы для семисегментов и запускает перемещение сегментов сервоприводами. Модуль управляет шаговыми состояниями: например, при срабатывании датчика движения он «включает» механизм поворота сегментов, передавая соответствующие сигналы в motors.v. Также ntp_clock.v вызывает модули обработки подсветки (color.v) и датчика движения (motion_detector.v), обеспечивая их синхронизацию.

## 6.3 Модуль collor.v.

Модуль управления светодиодной лентой. Он принимает 4-битное значение режима от ghrd_top (упакованное в старшую часть 32-битного слова) и на его основе формирует сигналы для RGB-вывода на соответствующие GPIO. В зависимости от текущего режима этот блок регулирует частоту импульсов, управляющих лентой, реализуя смену цвета.

## 6.4 Модуль seven_segment.v.

Декодер семисегментных индикаторов. Модуль преобразует двоичный код цифры (0–9), полученный из HPS, в сигналы для сегментов индикаторов. В проекте «часы» и «минуты» представлены двумя 7-сегментными устройствами, и для каждой цифры вызывается свой экземпляр модуля. Seven_segment.v обеспечивает правильную фазировку включения сегментов, чтобы на индикаторах отображались заданные цифры времени.

## 6.5 Модуль motors.v.

Модуль генерации сигнала PWM для сервоприводов. Для каждого сегмента часов/минут генерируется импульс соответствующей длительности, чтобы повернуть сервомотор на требуемый угол. По умолчанию предусмотрено два основных положения: 0° и 90° (значения «выключено/включено» для данного сегмента). Для тонкой подстройки физического положения сегментов в коде используется параметр ANGLE (например, .ANGLE(90)), который задаёт продолжительность импульса для положения 90°. Таким образом, после калибровки каждый сегмент может показывать часы и минуты корректно.

## 6.6 Прочие модули.

motion_detector.v – обрабатывает входной сигнал от датчика движения и выдаёт логический флаг, управляя сменой состояния сегментов часов. blink_led.v – мигает светодиодами между цифрами часов и минут, создавая визуальное разделение.

После написания модулей проект собирается в Quartus. Генерируется файл конфигурации FPGA (.sof), который можно загрузить через Quartus Programmer (USB-Blaster II). Для постоянного сохранения настроек создаётся файл .jic для прошивки флеш-памяти платы. При отладке удобно загружать .sof для быстрого тестирования, а в финальном варианте – прошивать .jic, чтобы часы стартовали автоматически после включения питания.

# 7 Разработка HPS-части (С, Python)

Аппаратная система HPS (ARM) работает под Ubuntu Linux запускаемой с SD-карты. Основные компоненты программной части:

## 7.1 Главная программа (main.c).

На языке C под Linux ARM написана программа, которая по расписанию получает текущее время от стандартной библиотеки time() и читает режим LED-ленты из текстового файла. Затем эти значения упаковываются в 32-битный регистр time_digits в формате:

uint32_t time_digits = ((uint32_t)color << 16)

| ((uint32_t)tens_hours << 12)

| ((uint32_t)ones_hours << 8)

| ((uint32_t)tens_minutes << 4)

| (uint32_t)ones_minutes;

Младшие 8 бит кодируют цифры часов и минут, старшие 16 бит – цвет подсветки. После упаковки main.c записывает это 32-битное слово в область памяти FPGA через Lite-AXI шину. В качестве адресного пространства используется PIO или раздел памяти, доступный через hps_0.h.

## 7.2 Доступ к аппаратуре FPGA.

Для взаимодействия с PIO-компонентами генерируется заголовочный файл hps_0.h с константами их базовых адресов (скриптом generate_hps_qsys_header.sh). В этом файле имеются макросы PIO_LED_BASE, PIO_MOTORS_BASE и др., указывающие адреса соответствующих регистров в адресном пространстве FPGA. В коде C к этим адресам можно обращаться через приведение указателей. Таким образом программа main.c напрямую управляет регистрами FPGA: записывая в них значение time_digits, она задаёт состояние семисегментов и сервоприводов, а также цвет LED-подсветки.

## 7.3 Кросс-компиляция.

Программа ARM-компонента компилируется под архитектуру ARM A9 с помощью GCC для ARM из комплекта SoC EDS. В Makefile указываются пути к заголовкам из SDK и опции кросс-компилятора. После компиляции получается исполняемый файл, который копируется на SD-карту.

## 7.4 Python-скрипт управления LED (API Zulip).

Дополнительно на ARM выполняется скрипт на Python (my_program.py), который подключается к чат-серверу Zulip и отслеживает поступающие команды. При получении нового сообщения скрипт извлекает из него цвет подсветки и записывает соответствующую цифру в тот же текстовый файл, который считывается main.c. Таким образом, администратор может удалённо менять цвет LED-ленты через чат. Для работы скрипта требуются библиотеки requests и синхронизация времени через протокол NTP.

## 7.5 Автозапуск демонов (systemd).

Чтобы часы автоматически стартовали при включении питания, создан systemd-сервис для Linux Ubuntu clock.service. В файле службы указаны пути для запуска основного исполняемого файла и Python-скрипта. После загрузки Ubuntu и подключения интернет-соединения, демон clock.service запускает часы в фоновом режиме и перезапускает их при необходимости.

# 8 Взаимодействие компонентов

## 8.1 Связь FPGA ↔ HPS.

Связь между FPGA и процессорной системой организована через шины Avalon. HPS имеет легковесный AXI master (h2f_lw), который позволяет напрямую адресовать регистры периферии FPGA. Например, C-программа записывает 32-битное слово времени и настроек в PIO-компонент, адресованный через сгенерированный хедер hps_0.h. В ghrd_top.v это слово принимается как входной регистр, который по отдельным битам распределяется по mодулю ntp_clock и далее по устройствам вывода. Таким образом, после каждой записи из ARM FPGA обновляет состояние семисегментов, сервоприводов и режим LED.

## 8.2 Управление сервоприводами.

Модуль motors.v создаёт на выходах FPGA импульсы ШИМ (Широтно-импульсная модуляция с фиксированной периодичностью (20 мс, соответствующая 50 Гц сервомотору). Ширина импульса задаётся значением параметра ANGLE в Verilog. Два ключевых уровня импульса соответствуют углам поворота сегмента 0° и 90°. В процессе отладки подбираются точные значения (см. раздел «Калибровка»). За счёт передачи управления через .ANGLE каждый сегмент настраивается индивидуально, что компенсирует механические допуски.

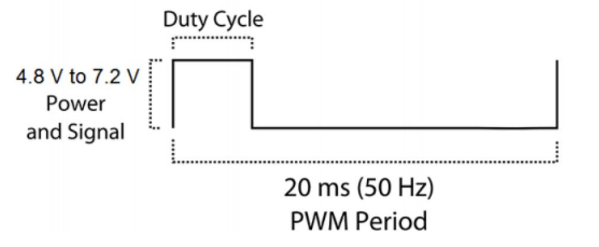
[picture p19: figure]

Рисунок 7. Устройство ШИМ-сигнала для сервопривода

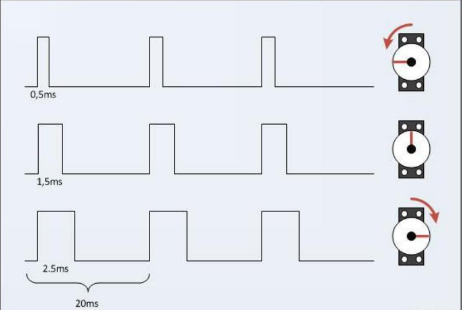
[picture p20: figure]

Рисунок 8. Пример ШИМ-сигнала для сервопривода

## 8.3 Управление семисегментными индикаторами.

Двоичный код цифры (0–9) от main.c подаётся на модуль seven_segment.v, который формирует 7 бит на сегменты. Числовой код разбивается на десятки и единицы, передаётся в соответствующие элементы модуля ghrd_top.v. Модуль seven_segment.v выдает активные сигналы сегментов, управляющие физическим показом цифры. Таким образом на индикаторах отображается правильно синхронизированное время. Например, младшие 4 бита пакета time_digits соответствуют единицам минут, следующие 4 бита – десяткам минут, и т.д.

## 8.4 Управление LED-подсветкой.

Команды цветов передаются ARM в FPGA через параметр color старших бит time_digits. Модуль color.v принимает это значение, декодирует режим и управляет GPIO для RGB-ленты (используя PWM). Python-скрипт позволит динамически менять это значение через сетевой чат. В итоге пользователь через Zulip может сменить цвет подсветки, и FPGA тут же переключит режим.

## 8.5 Датчик движения.

Сигнал от PIR-датчика поступает на один из входов GPIO FPGA. Модуль motion_detector.v отслеживает состояние и при появлении движения ставит флаг в ghrd_top, который передается в ntp_clock. Это запускает движение сегментов (часы «просыпаются» и выставляют сегменты в нужное положение в соответствии с текущим временем). Для тестирования в ModelSim используется искусственное изменение GPIO: в тестбенче по шаблону меняется вход GPIO, имитируя срабатывание датчика. При появлении сигнала движения $monitor фиксирует в консоли изменение внутренней переменной motion, и FPGA начинает работу механизмов.

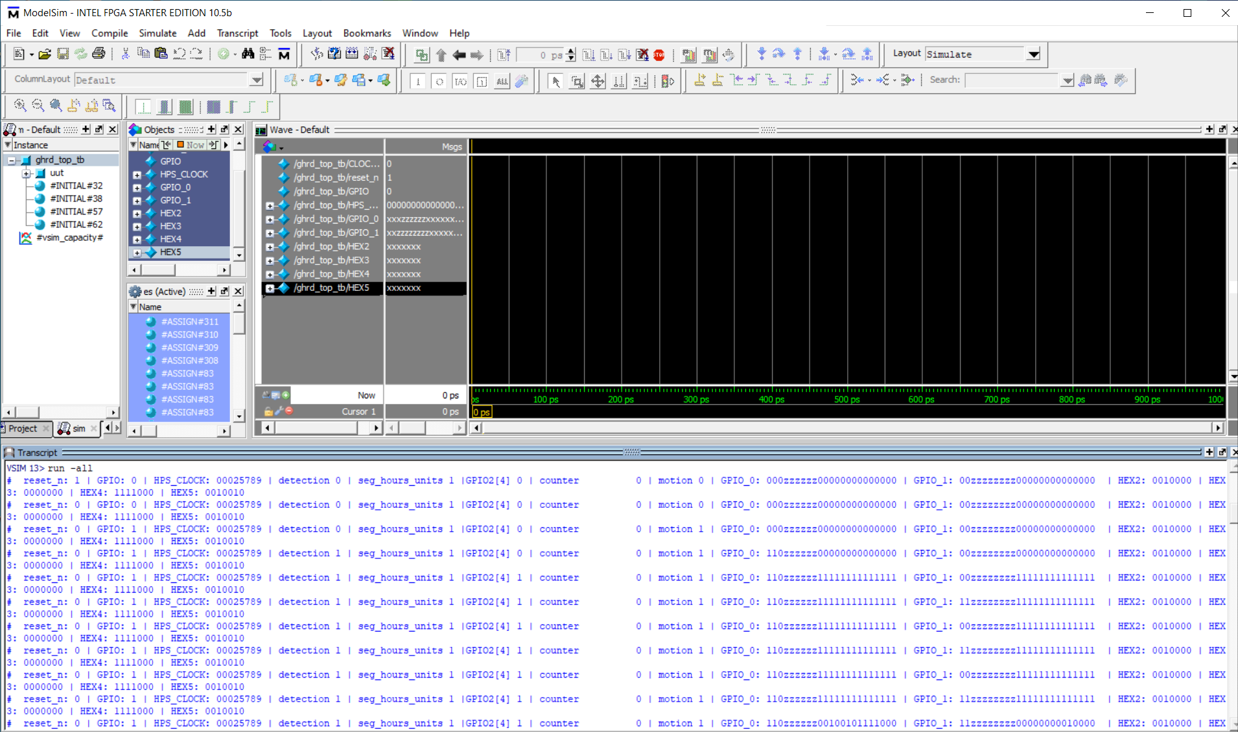
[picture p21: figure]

Рисунок 9. Сигналы на входе датчика движения и соответствующее изменение флага motion в тестовой симуляции

# 9 Отладка и калибровка

Для обеспечения корректной работы системы были проведены следующие процедуры:

## 9.1 Калибровка сервоприводов.

Поскольку механические сегменты печатаются 3D-принтером и имеют допуски, некоторые сегменты физически не могли работать корректно вместе с другими. Так, при постановке их в активное положение, некоторые сегменты мешали соседним выставиться в ровные цифры, не давали сервомоторам повернуться на полные 90 градусов, вследствие чего было принято решение регулировать углы поворота серводвигателей программно. В Verilog-коде модуля motors параметр .ANGLE задаёт длительность импульса на положение 90°. Путём изменения этого параметра в ntp_clock.v для каждого сегмента добились точного выравнивания. Например:

motors #(

.ANGLE(90)

) seg_minutes_tens (

.mclk(clk),

.control_input(seg_minutes_tens_data),

.reset(reset_n),

.main_program(main_program_flag),

.servo(GPIO1[...])

);

Меняя значение ANGLE, подбирается оптимальный PWM для каждого сервомотора. Это позволяет устранить погрешности печати и сборки

## 9.2 Симуляция в ModelSim.

Для верификации FPGA-логики использован тестбенч ghrd_top_tb.v. В нём создаются тактовый сигнал (50 МГц) и входные шаблоны: изменение HPS_CLOCK (имитация получения времени) и GPIO (имитация датчика движения). В ModelSim задаётся генерирующая конструкция:

initial begin

CLOCK_50 = 0;

forever #10 CLOCK_50 = ~CLOCK_50; // 50 MHz (20 нс период)

end

Это обеспечивает 50 MHz такт, который «горит» в waveform. Затем в среде симуляции наблюдают реакции выходов HEX и GPIO_0/1. Благодаря наличию $monitor в тестбенче в консоль выводятся сообщения при изменении ключевых сигналов. Такой тестовый запуск показал, что при подаче на GPIO сигнала «1» поднимался флаг motion, а при изменении HPS_CLOCK обновлялись значения выходов индикаторов.

## 9.3 Отладка ПО.

На уровне ARM при первоначальном запуске была проведена проверка работы main.c и Python-скрипта. С помощью консоли Linux убедились, что в файл записываются корректные коды цветов и на макете отображается корректное время. Также через JTAG-UART было реализовано получение вывода от FPGA для проверки чтения чисел.

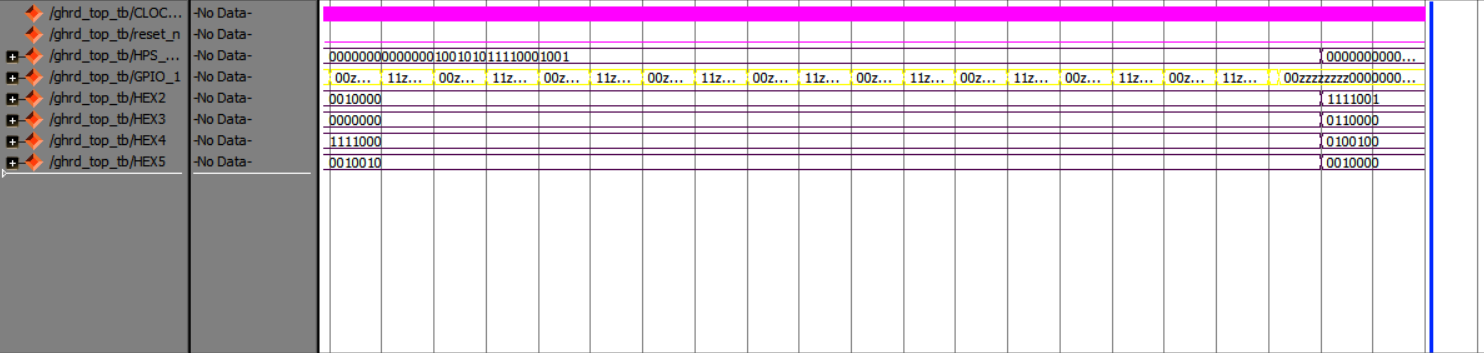
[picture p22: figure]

Рисунок 10. Моделирование в ModelSim: волновые формы сигнала CLOCK_50 и реакции выходов при изменении входа HPS_CLOCK

# 10 Возможности доработки проекта

По итогам курсовой работы были выявлены следующие проблемы:

- Несмотря на калибровку сервоприводов, сегменты не стоят ровно, так как им недостаёт питания, при каждом включении часов углы меняются.
- Периодически возникают помехи, из-за которых сегменты дёргаются, некоторые сервоприводы приходят в негодность, светодиоды «моргают» не синхронно, а LED-лента иногда меняет свой цвет.
- Издержки 3D-печати, ручной сборки и склеивания пластиковых деталей также вызывают неровности в положении сегментов.

# 11 Заключение

В рамках выполнения курсовой работы "Электромеханические часы на ПЛИС" был реализован проект, объединяющий цифровое и физическое отображение времени с использованием платы Terasic DE1-SoC. Был проведен сравнительный анализ возможностей FPGA и HPS для обработки данных времени, управления сервомоторами и взаимодействия с внешними устройствами. Была исследована эффективность интеграции аппаратных модулей Verilog с программным обеспечением на C и Python для достижения точного и надежного функционирования системы.

Важная особенность разработанной системы состоит в том, что она автоматически запускается при включении питания и активируется датчиком движения, что обеспечивает удобство использования и энергосбережение. Ввиду необходимости улучшения видимости дисплея были предложены и реализованы решения по добавлению LED-подсветки с удаленным управлением через чат Zulip. Были рассмотрены вопросы проектирования 3D-модели корпуса, состоящего из четырех частей, а также калибровки сервомоторов для точного отображения времени.

Разработан функциональный прототип электромеханических часов, который успешно сочетает цифровые семисегментные индикаторы и физические 3D-сегменты, управляемые сервомоторами. Проведенные тесты подтвердили стабильность системы, точность отображения времени и надежность всех компонентов. Отладка включала калибровку сервоприводов и симуляцию, что показало корректную работу всей системы. Такой проект иллюстрирует, как гибкая архитектура FPGA+ARM позволяет создавать сложные встраиваемые системы «с нуля».

По итогам работы был собран макет (рис. 11, 12), использующийся на днях открытых дверей и других мероприятиях МИЭМ и в частности программы «Информатика и вычислительная техника» для наглядной демонстрации изучаемых здесь дисциплин и предоставляемых возможностей, а также привлечения внимания абитуриентов. Также имеется репозиторий Github, где хранятся все файлы проекта, и документация пользователя и разработчика, благодаря чему любой желающий может повторить или адаптировать проект под свои нужды.

Таким образом, итоговый проект соответствует техническому заданию, работа демонстрирует практическое применение современных технологий ПЛИС для создания инновационных устройств с учетом требований удобства и функциональности. Это позволяет наглядно продемонстрировать изучаемые в МИЭМ принципы работы с ПЛИС, а также предоставляемые студентам возможности использования оборудования и веб-сервисов, таких как Zulip, института для реализации проектов, наглядного и непосредственного изучения встраиваемых систем.

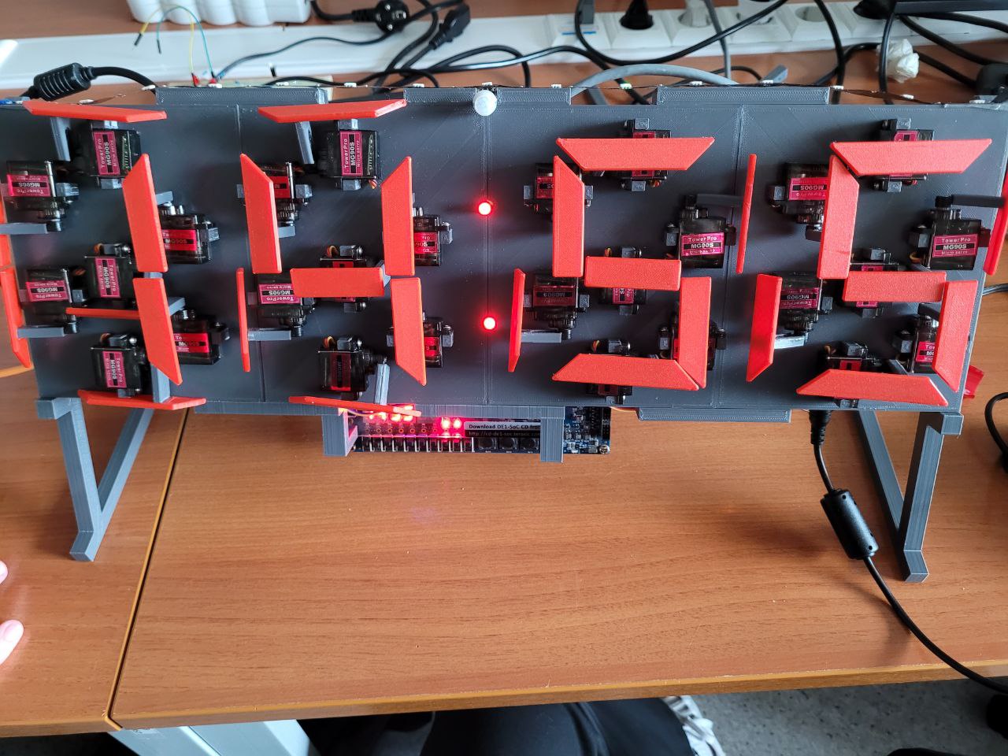
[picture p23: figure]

Рисунок 11. Итоговая версия курсовой работы.

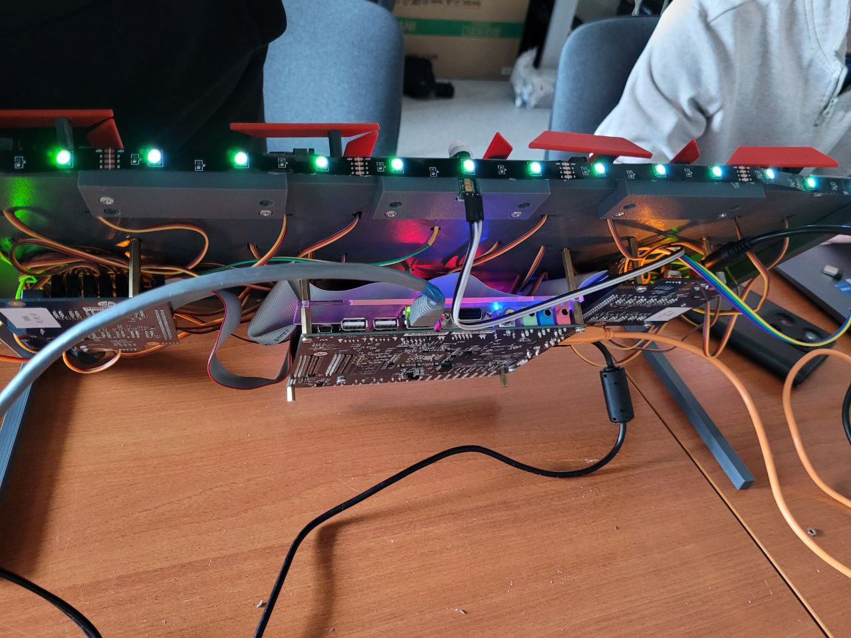
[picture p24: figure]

Рисунок 12. Итоговая версия курсовой работы.

# 12 Список использованных источников

1. Поднимаем Linux на MIPSfpga и ПЛИС Altera // Хабр [Электронный ресурс]. – URL: https://habr.com/ru/articles/333920/ (https://habr.com/ru/articles/333920/%20) (дата обращения 25.01.2025).
2. Репозиторий Github [Электронный ресурс]. – URL: https://github.com/Maxim364/- (дата обращения 15.05.2025).
3. Сервоприводные 7-сегментные часы на Arduino // AlexGyver Technologies [Электронный ресурс]. – URL: https://alexgyver.ru/servo-clock/ (https://alexgyver.ru/servo-clock/%20) (дата обращения: 27.01.2025).
4. Цифровой синтез: практический курс // под общ. ред. А. Ю. Романова, Ю. В. Панчула. – М.: ДМК Пресс, 2020. – 556 с.
5. Цифровая схемотехника и архитектура компьютера. Второе издание // Дэвид М. Харрис, Сара Л. Харрис. – Morgan Kaufman © English Edition 2013. – 1621 ‍с.
6. Часы на ПЛИС Lattice // Хабр [Электронный ресурс]. – URL: https://habr.com/ru/articles/275863/ (https://habr.com/ru/articles/275863/%20) (дата обращения 28.01.2025).
7. Часы на ПЛИС с применением Quartus II и немного Verilog // Хабр [Электронный ресурс]. – URL: https://habr.com/ru/articles/125364/ (https://habr.com/ru/articles/125364/%20) (дата обращения 28.01.2025).

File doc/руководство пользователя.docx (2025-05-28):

ФЕДЕРАЛЬНОЕ ГОСУДАРСТВЕННОЕ АВТОНОМНОЕ ОБРАЗОВАТЕЛЬНОЕ УЧРЕЖДЕНИЕ ВЫСШЕГО ОБРАЗОВАНИЯ

«НАЦИОНАЛЬНЫЙ ИССЛЕДОВАТЕЛЬСКИЙ УНИВЕРСИТЕТ

«ВЫСШАЯ ШКОЛА ЭКОНОМИКИ»

###### МОСКОВСКИЙ ИНСТИТУТ ЭЛЕКТРОНИКИ И МАТЕМАТИКИ

###### им. А.Н. ТИХОНОВА

Леснов Илья Андреевич, группа БИВ248

Батаев Максим Алексеевич, группа БИВ248

РУКОВОДСТВО пОЛЬЗОВАТЕЛЯ К ЭЛЕКТРОННО-МЕХАНИЧЕСКИМ ЧАСАМ НА ПЛИС

Курсовая работа

по направлению 09.03.01 Информатика и вычислительная техника

студентов образовательной программы бакалавриата
«Информатика и вычислительная техника»

Введение

Это руководство предназначено для пользователей, которые хотят настроить и использовать электромеханические часы. Система построена на плате Terasic DE1-SoC, которая включает FPGA (Cyclone V) и HPS (ARM Cortex-A9), работающий под управлением Linux (Ubuntu). Часы отображают время на семисегментных индикаторах и используют сервоприводы для физического отображения цифр при активации датчиком движения. Также имеется LED-подсветка, цвет которой регулируется с помощью определённого чата Zulip.

Подключение оборудования

Для начала работы необходимо правильно подключить все компоненты:

- Подключите источник питания 12v к плате Terasic DE1-SoC.
- Подключите источники питания 12v к платам Servo-motor-kit.
- Подключите платы Servo-motor-kit к ПЛИС с помощью шлейфов GPIO в соответствии со схемой подключения (рис. 1).
- Подключите сервоприводы, светодиоды, датчик движения, светодиодную ленту к платам Servo-motor-kit в соответствии со схемой подключения (рис. 1), пример подключения изображён на рисунке 2. (Цифры на схеме соответствуют обозначениям портов GPIO на платах SMK).
- Подключите кабель Ethernet в соответствующий порт на ПЛИС.


Рисунок 1. Схема подключения

…

Рисунок 2. Пример подключения

Загрузка образа Linux Ubuntu на плату

1. Переведите переключатели на обратной стороне платы в положение «00000».
2. Перейдите по ссылке [https://github.com/Maxim364/-/blob/main/linux_image/download_linux_image.txt] и скачайте готовый образ для SD-карты.
3. Вставьте SD-карту в компьютер.
4. Скачайте Win32 Disk Imager по ссылке [https://sourceforge.net/projects/win32diskimager/] и запустите программу.
5. Нажмите на значок папки и выберите скачанный файл (рис. 3).
6. В разделе "Device" выберите букву диска, соответствующую SD-карте (рис. 4).
7. Нажмите "Write" и дождитесь завершения процесса (рис. 5).
8. После завершения безопасно извлеките SD-карту.
9. Вставьте SD-карту в ПЛИС. Теперь при запуске платы система загрузится автоматически с SD-карты.


Рисунок 3. Выбор нужного файла в Win32.


Рисунок 4. Выбор диска, соответствующего съёмному носителю.


Рисунок 5. Кнопка «Write» в Win32.

Загрузка файла конфигурации на плату

1. Переведите переключатели на обратной стороне платы в положение «10010».
2. Перейдите по ссылке [https://github.com/Maxim364/-/tree/main/quartus_project/output_files] и скачайте файл конфигурации для ПЛИС в формате .jic.
3. Перейдите по ссылке [https://disk.yandex.ru/d/vBKJDuNFLoh1Jw] и скачайте Quartus.
4. В меню программы Quartus выберите инструмент «Programmer» (рис. 6).
5. Нажмите «Auto Detect».
6. Дважды щелкните на область, выделенную на рисунке (рис. 7), появится страница «Select New Programming File», после чего выберите нужный файл.
7. Отметьте соответствующие галочки в столбце «Program/Configure» (рис. 8), будет загружен заводской образ SFL по умолчанию.
8. Нажмите «Start», чтобы запрограммировать последовательное конфигурационное устройство.


Рисунок 6. Программатор в Quartus II.


Рисунок 7. Выбор нужного устройства.


Рисунок 8. Выбор устройства для программирования.

Включение системы

Чтобы включить часы, нажмите на красную кнопку включения ПЛИС на её фронтальной стороне. Система автоматически загрузится и запустит необходимые программы. Часы начнут отображать время на семисегментных индикаторах, а сервоприводы будут двигаться, отображая цифры времени при обнаружении движения.

Использование часов

Часы активируются при обнаружении движения датчиком. Через 2 минуты бездействия система выключается. Время отображается на индикаторах HEX2-HEX5, а сервоприводы физически показывают цифры.

Имеется возможность менять цвет подсветки с помощью чат-бота в Zulip. Для этого необходимо зайти в чат по ссылке [https://chat.miem.hse.ru/#narrow/stream/2405-test11] и отправить боту сообщение с желаемым цветом (имеются 4 варианта: red, green, blue и off).

Возможности редактирования устройства

В репозитории [https://github.com/Maxim364/-] присутствуют файлы 3D-модели частей корпуса, креплений и сегментов часов, созданные в программе Компас-3D. При необходимости они могут быть отредактированы и перепечатаны на 3D-принтере.

Устранение неполадок

Если часы не отображают время, проверьте правильность подключения проводов в соответствии со схемой подключения (рис. 1).

При некорректном отображении времени убедитесь, что есть доступ в интернет для синхронизации времени.

Программой предусмотрено отображение статуса работы датчика движения и непосредственно часов на встроенных светодиодах ПЛИС, проверьте, что оба светодиода горят.

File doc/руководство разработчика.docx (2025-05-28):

ФЕДЕРАЛЬНОЕ ГОСУДАРСТВЕННОЕ АВТОНОМНОЕ ОБРАЗОВАТЕЛЬНОЕ УЧРЕЖДЕНИЕ ВЫСШЕГО ОБРАЗОВАНИЯ

«НАЦИОНАЛЬНЫЙ ИССЛЕДОВАТЕЛЬСКИЙ УНИВЕРСИТЕТ

«ВЫСШАЯ ШКОЛА ЭКОНОМИКИ»

###### МОСКОВСКИЙ ИНСТИТУТ ЭЛЕКТРОНИКИ И МАТЕМАТИКИ

###### им. А.Н. ТИХОНОВА

Леснов Илья Андреевич, группа БИВ248

Батаев Максим Алексеевич, группа БИВ248

РУКОВОДСТВО РАЗРАБОТЧИКА К ЭЛЕКТРОННО-МЕХАНИЧЕСКИМ ЧАСАМ НА ПЛИС

Курсовая работа

по направлению 09.03.01 Информатика и вычислительная техника

студентов образовательной программы бакалавриата
«Информатика и вычислительная техника»

Содержание

1. Введение
2. Аппаратная часть
  2.1. Схема подключения
  2.2. Quartus
  2.3. Platform designer (QSYS)
  2.4. 3D-модель и корпус (Компас-3D)
3. Разработка FPGA (Verilog)
  3.1. Модуль ghrd_top.v
  3.2. Модуль ntp_clock.v
  3.3. Модуль collor.v
  3.4. Модуль seven_segment.v
  3.5. Модуль motors.v
  3.6. Прочие модули
4. Разработка HPS-части (Linux Ubuntu)
  4.1. Подготовка образа Ubuntu на SD-карте
  4.2. Программа main.c: запись времени и режим LED
  4.3. Кросс-компиляция C-программы (Makefile)
  4.4. Python-скрипт управления подсветкой (API Zulip)
  4.5. Демоны systemd для автозапуска
5. Отладка и калибровка
  5.1. Калибровка углов сервоприводов
  5.2. Симуляция в ModelSim
6. Устранение неполадок

1. Введение

В данном руководстве подробно описан процесс разработки и развёртывания электронно-механических часов на платформе Terasic DE1-SoC, включающей FPGA Cyclone V и HPS (ARM Cortex-A9 под Ubuntu Linux). Система отображает текущее время на семисегментных индикаторах, переводит цифры в физическое движение сервоприводов при активации датчиком движения и управляет цветом LED-ленты через API Zulip МИЭМ.

Ссылка на репозиторий GitHub: https://github.com/Maxim364/-

Проект QSYS: soc_system.qsys (Quartus Prime 17.1, Platform Designer 17.1.1).

2. Аппаратная часть

2.1. Схема подключения (рис. 1)

- Подключите 12 В питание к разъёму питания DE1-SoC.
- Подключите питание 12 В, не менее 5 А к платам сервоприводов.
- Шлейфами GPIO соедините кнопки, LED-ленту, датчик движения и сервоприводы по схеме:
- DE1-SoC GPIO0[0..13] → сервоприводы часов
- DE1-SoC GPIO1[0..13] → сервоприводы минут
- DE1-SoC GPIO0[20..22] → LED-подсветка
- DE1-SoC GPIO0[23] → датчик движения
- DE1-SoC GPIO1[22, 23] → разделительные светодиоды
- Подключите Ethernet-кабель к разъёму RJ45 для доступа в интернет.


Рисунок 1: схема подключения

2.2 Quartus

Проект создаётся с помощью SystemBuilder. Для создания скачайте папку SystemBuilder [https://disk.yandex.ru/d/GX9w3LY5XOABFA], запустите DE1SoC_SystemBuilder.exe. В появившемся окне выберите компоненты в соответствии с рисунком 2. Далее нажмите кнопку Generate, генерируется проект. Этот проект включает все необходимые объявления выводов для HPS и FPGA. Проект также включает базовую систему Qsys, которая уже включает компонент HPS. Компонент HPS был сконфигурирован в соответствии с аппаратным проектом DE1-SoC HPS.

Рисунок 2. Компоненты автогенерации проекта.

2.3. Platform Designer (QSYS)

Откройте систему Qsys, открыв проект Quartus и щелкнув пункт меню «Tools» → «Platform Designer» (Рис. 3). При запуске инструмента Qsys он попросит пользователя выбрать целевой системный файл Qsys. Это окно нужно закрыть, тогда создастся новый файл или создать его через «File → New System» (Рис. 4).


Рисунок 3. Platform Designer в Quartus.

Рисунок 4. Создание новой системы QSYS.

Далее необходимо добавить компонент PIO в Qsys и подключить компонент PIO к компоненту HPS. Компонент PIO используется для управления сервомоторами, светодиодами и датчиком движения, подключенными к FPGA. Сначала скопируйте проект Quartus на диск. Откройте проект и откройте системный файл Qsys «soc_system.qsys». В диалоговом окне Library инструмента Qsys введите ключ поиска „pio‟, как показано на рисунке 5. Когда появится «PIO (Parallel I/O)», выберите его. Затем нажмите «Add…», чтобы добавить компонент PIO в систему.


Рисунок 5. Поиск и добавление компонента PIO.

Когда появится диалоговое окно PIO, измените ширину на 10, убедитесь, что выбрано направление «Output», и измените значение сброса выходного порта на 0x3ff, как показано на рисунке 6. Когда компонент PIO добавлен в систему, подключите главный порт AXI h2f_lw_axi_master к подчиненному порту s1 компонента PIO, как показано на рисунке 7. Измените имя компонента PIO на pio_led, измените вход Clock на clk_0, экспортируйте Conduit сигнал как pio_led_external_connection и подключите вход сброса к системному сбросу. О братите внимание, что базовый адрес компонента PIO pio_led очень важен. Программа ARM будет обращаться к компоненту в соответствии с этим базовым адресом. В этой демонстрации базовый адрес зафиксирован на 0x0000_0000. Разработчик программы ARM должен запомнить этот базовый адрес или использовать заданный пакетный файл оболочки Linux для извлечения информации об адресе в заголовочный файл hps_0.h.


Рисунок 6. Настройка PIO компонента.

Рисунок 7. Создание соединения между компонентом HPS и PIO.

В инструменте Qsys щелкните пункт меню «Generate → Show instantiation template», чтобы найти новый интерфейсный сигнал pio_led_external_connection_export для добавленного компонента PIO pio_led, как показано на рисунке 8. Разработчик может щелкнуть «Копировать», чтобы скопировать с одержимое в буфер обмена, затем вставить сигнал pio_led_external_connection_export в верхнюю часть Quartus и подключить его к порту LEDR. Аналогично следует добавить, настроить и соединить остальные блоки, как показано на рисунках 9.1-9.16, а также указать базовые адреса. Перед закрытием инструмента Qsys не забудьте щелкнуть пункт меню «Generate → Generate HDL…», чтобы сгенерировать исходный код для системы.


Рисунок 8. pio_led интерфейс системы


Рисунок 9.1. Настройки компонентов в QSYS


Рисунок 9.2. Настройки компонентов в QSYS

Рисунок 9.3. Настройки компонентов в QSYS


Рисунок 9.4. Настройки компонентов в QSYS


Рисунок 9.5. Настройки компонентов в QSYS


Рисунок 9.6. Настройки компонентов в QSYS

Рисунок 9.7. Настройки компонентов в QSYS


Рисунок 9.8. Настройки компонентов в QSYS


Рисунок 9.9. Настройки компонентов в QSYS


Рисунок 9.10. Настройки компонентов в QSYS

Рисунок 9.11. Настройки компонентов в QSYS


Рисунок 9.12. Настройки компонентов в QSYS


Рисунок 9.13. Настройки компонентов в QSYS


Рисунок 9.14. Настройки компонентов в QSYS

Рисунок 9.15. Связи компонентов в QSYS


Рисунок 9.16. Связи компонентов в QSYS

Таблица связи IP-блоков:

IP-блок | Имя интерфейса | Тип интерфейса | Базовый адрес | Конечный адрес
HPS | hps_0 | AXI Master | 0x00000000 | 0xffffffff
PIO (LED) | pio_led | AXI Lite Slave | 0x00000000 | 0x0000000f
JTAG to Avalon Master Bridge | hps_only_master | AXI Lite Slave | - | -
System ID | sysid_qsys | AMM Slave | 0x00010000 | 0x00010007
Onchip-memory | onchip_memory2_0 | AMM Slave | 0x00000000 | 0x0000ffff
JTAG UART | jtag_uart | AMM Slave | 0x00020000 | 0x00020007
JTAG to Avalon Master Bridge | fpga_only_master | AMM Master | - | -
Clock source | clk_0 | PIO | - | -

Генерация файлов:

После генерации .qsys, Quartus создаёт:

- .sopcinfo — структура системы, можно открыть в обычном текстовом редакторе.
- .qip, .vhd/.v — подключение в топ-модуль FPGA.

Далее нужно добавить файлы .qip в проект. Чтобы это сделать перейдите в «Project → Add/Remove Files in Project…» в верхней части окна. В появившемся окне выберите файл .qip и нажмите «Add all», а затем Ok.

2.4. 3D-модель и корпус (Компас-3D)

Для механической части часов разработана 3D-модель корпуса, креплений и сегментов в Компас-3D, с CAD-файлами: четыре части корпуса, ножка, крепления сервомоторов, подставки, сегменты цифр. Детали экспортированы в STL и подготовлены к 3D-печати (слой 0.2 мм, 20 % заполнение, PLA). Конструкция обеспечивает точное позиционирование моторов и сегментов.

В ходе работы модель улучшалась: укреплялись соединения из-за веса плат DE1-SoC, SMK и сервомоторов; дорабатывались крепления сегментов и корпуса для устранения проблем с движением, вызванных шероховатостью и неточностями сборки.

Всего в сборке 99 элементов: 3 габаритных экземпляра плат (1 DE1-SoC и 2 SMK), 28 сервомоторов, 28 креплений сегментов, 28 сегментов (8 Сегментов 1, 8 Сегментов 2, 8 Сегментов 4, 4 Сегмента 3), 4 части корпуса, 6 креплений корпуса (Крепление 1, Крепление 2, Крепление 3, 3 Крепления 4), 2 подставки корпуса. Из них 68 напечатаны на 3D-принтере.

Для объединения элементов в сборку были использованы сопряжения. Элемент Крепление сегмента крепится к элементу Сегмент с помощью сопряжений «Совпадение»: верхняя плоскость Крепления сегмента крепится к плоскости выемки Сегмента, и «Расстояние»: две боковые перпендикулярные плоскости Сегмента устанавливаются на расстоянии 0 от соответствующих плоскостей Крепления сегмента. Сервомоторы устанавливаются с помощью сопряжений «Совпадение», применяемых между нижней плоскостью Сервомотора и Верхней плоскости Корпуса, а также между вертикальными плоскостями специальных выпуклых элементов Корпуса и Сервомоторов. Сервомоторы имеют специальные насадки, закрепляющиеся с помощью инструментов «Соосность» и «Совпадение». Сегменты с Креплениями крепятся к Сервомоторам с помощью сопряжения «Совпадение» между плоскостями выемки на Креплении и насадок. При желании можно добавить сопряжение «Расстояние» или «Под углом», ограничивающее движение насадки и Сегмента с Креплением до плоскости Корпуса. Подставки корпуса крепятся с помощью сопряжения «Совпадение» между прилегающими плоскостями и «Соосность» между отверстиями на Корпусе и Подставках. Аналогично крепятся Крепления корпуса. Части корпуса крепятся с помощью сопряжения «Совпадение» между прилегающими плоскостями и креплениями.

После создания сборки и редактирования каждого элемента в зависимости от нужд, детали можно напечатать на 3D-принтере. Для этого:

1. Сохраните каждую деталь в формат .stl: Файл → Сохранить как…→ Тип файла: .stl.
2. Загрузите STL в программу слайсинга (например, Cura).
3. Настройте: слой 0.2 мм, заполнение 20 %, температура 200 °C.
4. Печатайте на FDM-принтере PLA материалом.

3. Разработка FPGA (Verilog)

Модули на языке Verilog создаются в проекте Quartus с помощью «File → New… → Verilog HDL File → Ok».

3.1. Модуль ghrd_top.v

Модуль ghrd_top.v отвечает за связь ПЛИС и HPS, в нём принимается 32-битное значение из программы на Си, также в нем объявляются входы и выходы системы и происходит взаимодействие между остальными модулями.

После завершения настройки всех файлов скомпилируйте файл ghrd_top.v. Для этого в окне «Quartus → Project Navigator» выберите «Files». Нажмите правой кнопкой мыши по файлу ghrd_top.v → «Set as Top-Level Entity». Затем в верхней панели инструментов нажмите «Start Compilation».

3.2. Модуль ntp_clock.v

Модуль ntp_clock.v – основная логика программы, преобразование данных времени в сигналы для семисегментных индикаторов, отправка их на каждый сервомотор, вызов модулей по работе подсветки, светодиодов и датчика движения.

3.3. Модуль collor.v

Модуль collor.v обрабатывает принимаемое значение из модуля ghrd_top.v для регулировки режима работы светодиодной ленты.

3.4. Модуль seven_segment.v

Модуль seven_segment.v отвечает за перевод цифр, полученных из HPS в сигналы для семисегментных индикаторов.

3.5. Модуль motors.v

Модуль motors.v генерирует PWM сигнал для каждого сервопривода в зависимости от времени. Каждый сегмент имеет 2 состояния: 0 и 90 градусов (для каждого сервопривода сигнал может различаться после калибровки для выравнивания сегментов)

3.6. Прочие модули

motion_detector.v — получение и обработка сигнала датчика движения для управления всей программой.

blink_led.v — моргание светодиодов между цифрами часов и минут.

3.7. Конфигурация FPGA: .sof и .jic файлы

Теперь необходимо сгенерировать файлы для выполнения платой, для этого нужно начать процесс компиляции, нажав на пункт меню «Processing → Start compilation». Когда процесс компиляции завершится успешно, soc_system.sof будет сгенерирован. Разработчики могут использовать этот файл для настройки ПЛИС с помощью Quartus Программатор через в строенный USB-Blaster II DE1-SoC.

Далее чтобы преобразовать файл в .jic нужно выбрать пункт меню «File → Convert Programming File» (рис. 10). В диалоговом окне «Convert Programming Files» перейдите к файлу «JTAG Indirect Configuration File (.jic)» в поле «Programming file type» В поле «Configuration Device» выберите «EPCQ256». В поле «Mode» выберите «Active Serial x4». В поле «File name» перейдите в целевой каталог и укажите имя выходного файла. Выделите данные SOF в разделе «Input files to convert». Нажмите кнопку «Add file» (рис. 11). Выберите SOF, который нужно преобразовать в файл JIC. Нажмите «Open». Выделите «Flash Loader» и нажмите «Add Device» (рис. 12). Нажмите OK. Откроется страница «Select Devices». Выберите «Device Family» «Cyclone V» и «Device name» «…» . Нажмите OK. Отобразится страница «Convert Programming Files». Нажмите кнопку «Generate».

Далее с помощью Quartus Programmer загружаем файл конфигурации на плату (.sof рекомендуется использовать для отладки и тестирования, а .jic для загрузки итогового проекта, так как он сохраняется во флеш-памяти платы, а .sof работает в пределах одного запуска). Для этого переведите переключатели на обратной стороне платы в положение «10010». В меню программы Quartus выберите инструмент «Programmer» (рис. 13). Нажмите «Auto Detect». Дважды щелкните на область столбца «File» <none>, появится страница «Select New Programming File», после чего выберите нужный файл. Отметьте соответствующее устройство в столбце «Program/Configure» (рис. 14), будет загружен заводской образ SFL по умолчанию. Нажмите «Start», чтобы запрограммировать последовательное конфигурационное устройство.


Рисунок 10. Открытие инструмента для конвертации файлов.


Рисунок 11. Добавление .sof файла.

Рисунок 12. Добавление ПЛИС для конфигурации.


Рисунок 13. Программатор в Quartus.


Рисунок 14. Выбор устройства для программирования.

4. Разработка HPS-части (Linux Ubuntu)

4.1. Подготовка образа Ubuntu на SD-карте

- Переведите переключатели на обратной стороне платы в положение «00000».
- Перейдите по ссылке […] и скачайте готовый образ для SD-карты.
- Вставьте SD-карту в компьютер.
- Скачайте Win32 Disk Imager по ссылке и запустите программу.
- Нажмите на значок папки и выберите скачанный файл (рис. 15).
- В разделе "Device" выберите букву диска, соответствующую SD-карте (рис. 16).
- Нажмите "Write" и дождитесь завершения процесса (рис. 17).
- После завершения безопасно извлеките SD-карту.
- Вставьте SD-карту в ПЛИС. Теперь при запуске платы система загрузится автоматически с SD-карты.


Рисунок 15. Выбор нужного файла в Win32.

Рисунок 16. Выбор диска, соответствующего съёмному носителю.


Рисунок 17. Кнопка «Write» в Win32.

4.2. Программа main.c: запись времени и режим LED

В программе происходит считывание текущего времени с помощью библиотеки time и режима работы LED-ленты из текстового файла, и упаковка в 32-битное значение.

uint32_t time_digits = ((uint32_t)collor << 16) | ((uint32_t)tens_hours << 12) | ((uint32_t)ones_hours << 8) | ((uint32_t)tens_minutes << 4) | (uint32_t)ones_minutes;

4.3. Кросс-компиляция C-программы (Makefile)

Информация о компоненте pio_led необходима для программы ARM C, поскольку программа будет пытаться управлять этим компонентом.

Далее нужно использовать заданный пакетный файл оболочки Linux для извлечения информацию из Qsys HPS в заголовочный файл, который позже будет включен в программу на языке C. Пакетный файл, упомянутый выше, называется generate_hps_qsys_header.sh. Он находится в той же папке, что и проект Quartus. Чтобы с генерировать файл заголовка, запустите командную оболочку Altera SoC EDS, в WSL перейдите в папку проекта Quartus (fpga-rtl) и выполните generate_hps_qsys_header.sh, введя «./generate_hps_qys_header.sh» и нажав клавишу ENTER. Генерируется файл заголовка hps_0.h . В файле заголовка базовый адрес pio_led представлен константой PIO_LED_BASE. Ширина pio_led представлена константой PIO_LED_DATA_WIDTH. Эти две константы будут использоваться в коде программы на языке C.

Проект может быть собран только с помощью кросс-компилятора, для которого прописан Makefile. Для корректной компиляции и работы С-программы на ПЛИС необходим SoC-EDS - комплексный набор инструментов для разработки встроенного программного обеспечения на Intel SoC FPGA, его можно скачать по ссылке: https://www.intel.com/content/www/us/en/software-kit/665461/intel-soc-fpga-embedded-development-suite-soc-eds-standard-edition-software-version-18-1-for-windows.html

Содержимое Makefile:

TARGET = my_first_hps-fpga - Задаётся имя исполняемого файла (результат сборки)

ALT_DEVICE_FAMILY = soc_cv_av — используется для указания семейства FPGA (Cyclone V SoC).

HWLIBS_ROOT — путь к заголовочным файлам аппаратных библиотек HPS (Qsys / Platform Designer IP библиотеки для ARM ядра).

SOCEDS_ROOT — переменная среды для корня SoC EDS (System-on-Chip Embedded Design Suite).

CROSS_COMPILE = /mnt/c/Users/01/cross/gcc-linaro-7.4.1-2019.02-x86_64_arm-linux-gnueabihf/bin/arm-linux-gnueabihf-

CC = $(CROSS_COMPILE)gcc

ARCH = arm

Здесь указывается непосредственно кросс-компилятор, он компилирует под ARM Linux, даже если сборка идёт на Windows или Linux x86.

Флаги компиляции:

CFLAGS = -nostartfiles -g -Wall -D$(ALT_DEVICE_FAMILY) -I$(HWLIBS_ROOT)/$(ALT_DEVICE_FAMILY) -I$(HWLIBS_ROOT)

LDFLAGS = -g -Wall

-nostartfiles — не подключать стандартные файлы запуска crt0.o (если система запускается не через libc).

-g — включить debug info.

-Wall — включить все предупреждения.

-D$(ALT_DEVICE_FAMILY) — добавить define soc_cv_av.

-I... — добавить директории с заголовочными файлами (для доступа к аппаратным регистрам HPS).

Установите кросс-компилятор по ссылке: ссылка

Перейдите в папку проекта:

cd путь/к/проекту

Чтобы скомпилировать проект, введите make

Введите ls, чтобы проверить сгенерированный исполняемый файл ARM.

4.4. Python-скрипт управления подсветкой (API Zulip)

Здесь программа считывает последнее сообщение из чата Zulip и в зависимости от цвета записывает в текстовый файл цифру.

Для корректной работы с запросами обновите сетевые протоколы с помощью команд:

sudo apt-get update

sudo apt-get install ntp

sudo systemctl enable ntp

Установите зависимости:

pip3 install requests

При необходимости есть возможность сменить данные для Zulip API на свои.

4.5. Демоны systemd для автозапуска

Переместите файлы my_first_hps-fpga и my_program.py на SD-карту

Вставьте карту в плату

С помощью USB-Mini подключите ваш компьютер к плате.

Скачайте программу PuTTY по ссылке [https://www.putty.org/]

Откройте PuTTY, установите настройки как на рисунке 18, нажмите Open.

Вы открыли терминал Linux Ubuntu платы на компьютере. Следующие команды пишутся в нём.

Скопируйте файлы из директории карты в корневую директорию

sudo cp -a /mnt/media/. /

Теперь нужно выдать права на исполнение файлам:

chmod +x my_first_hps-fpga

chmod +x my_program.py

Создайте файл с помощью команды sudo nano /etc/systemd/system/clock.service:

[Unit]

Description=Автозапуск программы часов

After=network.target

[Service]

ExecStart=/main.o && /usr/bin/python3 /my_program.py

Restart=always

User=root

[Install]

WantedBy=multi-user.target

Активируйте:

sudo systemctl daemon-reload

sudo systemctl enable clock.service

sudo systemctl start clock.service


Рисунок 18 Настройки PuTTY.

5. Отладка и калибровка

5.1. Калибровка углов сервоприводов

Путём изменения значения углов в модуле ntp_clock.v можно откалибровать наклон сегментов часов и устранить неровные места, возникшие из-за издержек 3д-печати и сборки. Для этого можно менять значение угла поворота .ANGLE(..), чтобы добиться наилучшего результата.

motors #(

.ANGLE(90)

)seg…(

.mclk(clk),

.control_input(seg_minutes_tens[…]), //Use this as the control input

.reset(reset_n),

.main_program(main_program),

.servo(GPIO…[…])

);

За счёт этого в модуле motors.v меняется время подачи сигнала, отправляемого на сервомоторы и угол регулируется.

5.2. Симуляция в ModelSim

Для отладки и тестовых запусков проекта используется modelsim. Его цель — симулировать поведение реальной схемы, подавая тестовые сигналы на входы и наблюдая отклики на выходах. Файл ghrd_top_tb.v

module ghrd_top_tb; — объявление тестового модуля.

Здесь создаются:

входные сигналы (как reg): CLOCK_50, reset_n, GPIO, HPS_CLOCK.

выходные сигналы (как wire): GPIO_0, GPIO_1, HEX2, HEX3, HEX4, HEX5.

Экземпляр тестируемого устройства uut (unit under test) подключает ghrd_top через порты.

initial begin

CLOCK_50 = 0;

forever #10 CLOCK_50 = ~CLOCK_50; // 50 МГц (период 20 нс, т.к. каждые 10 нс меняется уровень)

end

Здесь создаётся такт 50 MHz. Каждые 10 нс сигнал меняется → полный цикл (0→1→0) за 20 нс = 50 MHz. В ModelSim можно будет видеть, что CLOCK_50 "моргает".

Инструкция по работе в modelism:

1. Запуск ModelSim GUI:
- Запустите ModelSim (или Intel ModelSim, или QuestaSim).
- В стартовом окне выберите:
  - File → New → Project
  - Дайте имя проекту, выберите папку.
  - Нажмите OK.
- Далее в окне будет предложено добавить существующие файлы, выберите:
  - ghrd_top.v
  - ghrd_top_tb.v
  - а также другие модули, на которые ссылается ghrd_top
2. Компиляция файлов
- В панели проекта выделите все файлы
- Нажмите Compile → Compile Selected.
- Убедитесь, что нет ошибок (зелёные галочки в списке файлов).
- Если появятся ошибки, откройте log-компиляции и исправьте.
3. Запуск симуляции
- В верхнем меню выберите Simulate → Start Simulation.
- В появившемся списке work library → ghrd_top_tb.
- Выделите ghrd_top_tb и нажмите OK.

Откроется главное окно симуляции.

4. Добавление сигналов в waveform

Сейчас окно волновых диаграмм пустое.

Чтобы добавить сигналы:

- В панели Objects выделите список сигналов модуля ghrd_top_tb.
- Правая кнопка → Add → To Wave → Selected Signals.
5. Запуск симуляции
- В верхней панели нажмите Run → Run All.
6. Сохранение и экспорт

Чтобы сохранить waveform:

File → Save Format (сохраняется .wlf файл проекта).

Или File → Export → Waveform Image (картинка).

Так как в проекте есть $monitor, внизу (в Transcript) будут печататься текстовые сообщения при изменении сигналов.

Данный тест проверяет: реакцию ghrd_top на изменения GPIO (имитация движения), реакцию на HPS_CLOCK (например, установка времени), видимость внутренних состояний (флаги main_program, motion, счётчики), корректность вывода на HEX2…HEX5 и GPIO_0, GPIO_1.

6. Устранение неполадок

Если семисегменты не показывают цифры → проверьте правильность адреса PIO и права /dev/mem.

Если сервоприводы не двигаются → убедитесь в корректности сигналов main_program и ANGLE.

Если LED-лента не реагирует → проверьте API-ключ Zulip и сетевое соединение.

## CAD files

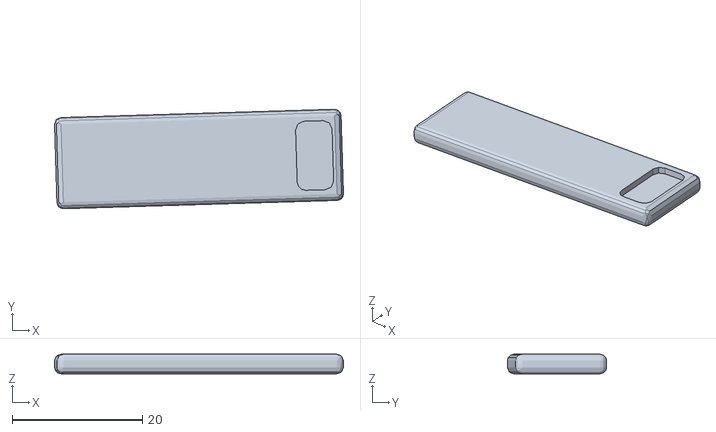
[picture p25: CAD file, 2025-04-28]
models/stl/сегмент3_x4.stl
44.3 x 15.3 x 3.00

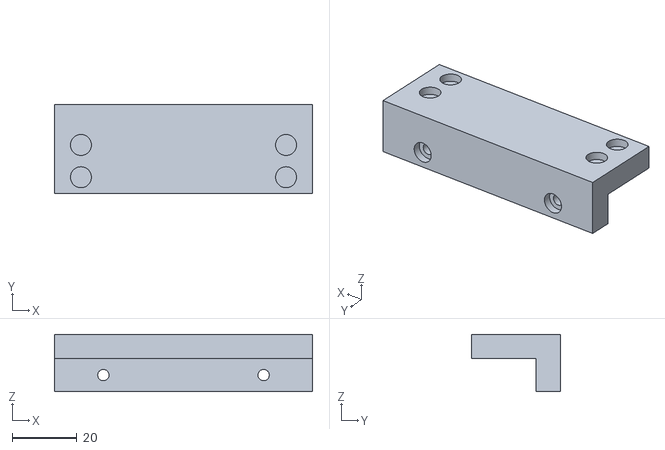
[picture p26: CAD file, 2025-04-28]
models/stl/плашках_х3.stl
80.0 x 27.5 x 17.7

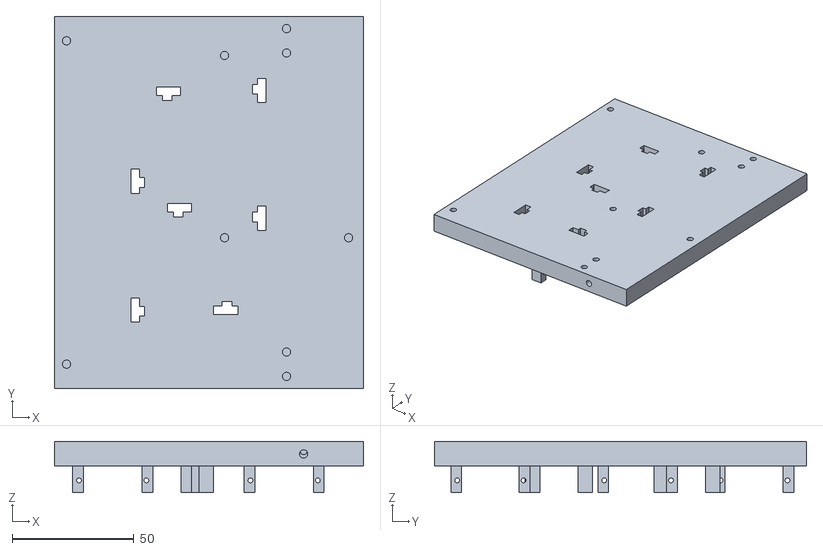
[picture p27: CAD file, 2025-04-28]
models/stl/корпус_часть_1.stl
127.2 x 153.0 x 21.0

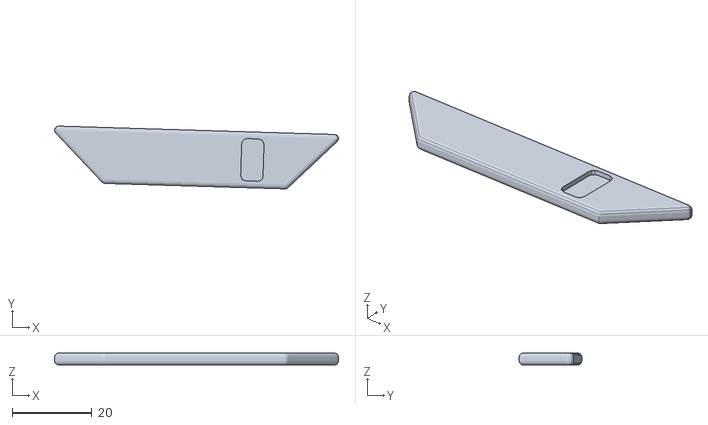
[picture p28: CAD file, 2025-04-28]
models/stl/сегмент1_х8.stl
71.1 x 15.7 x 3.00

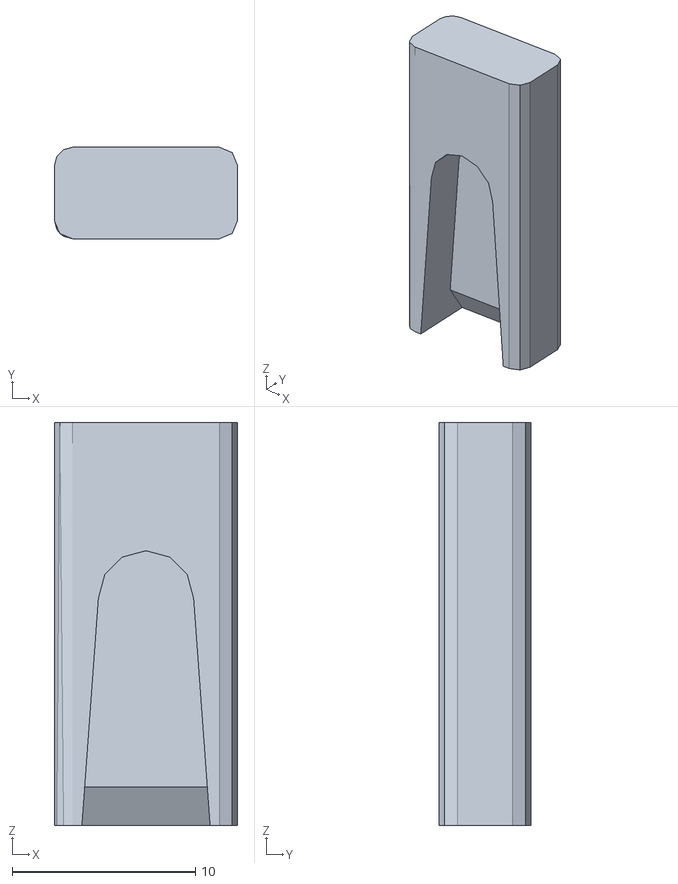
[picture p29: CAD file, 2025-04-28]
models/stl/ножка_х28.stl
10.0 x 5.00 x 22.0

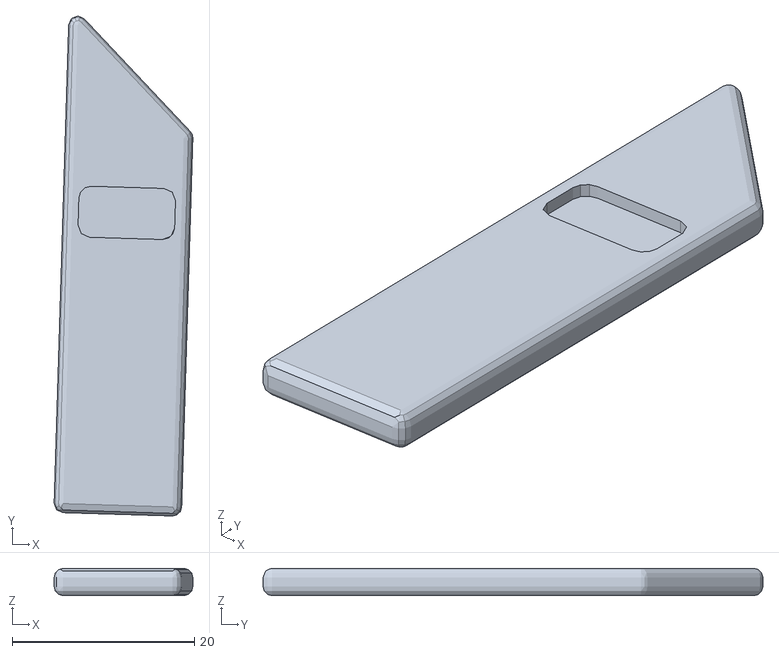
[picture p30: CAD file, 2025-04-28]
models/stl/сегмент4_x8.stl
15.2 x 54.8 x 3.00

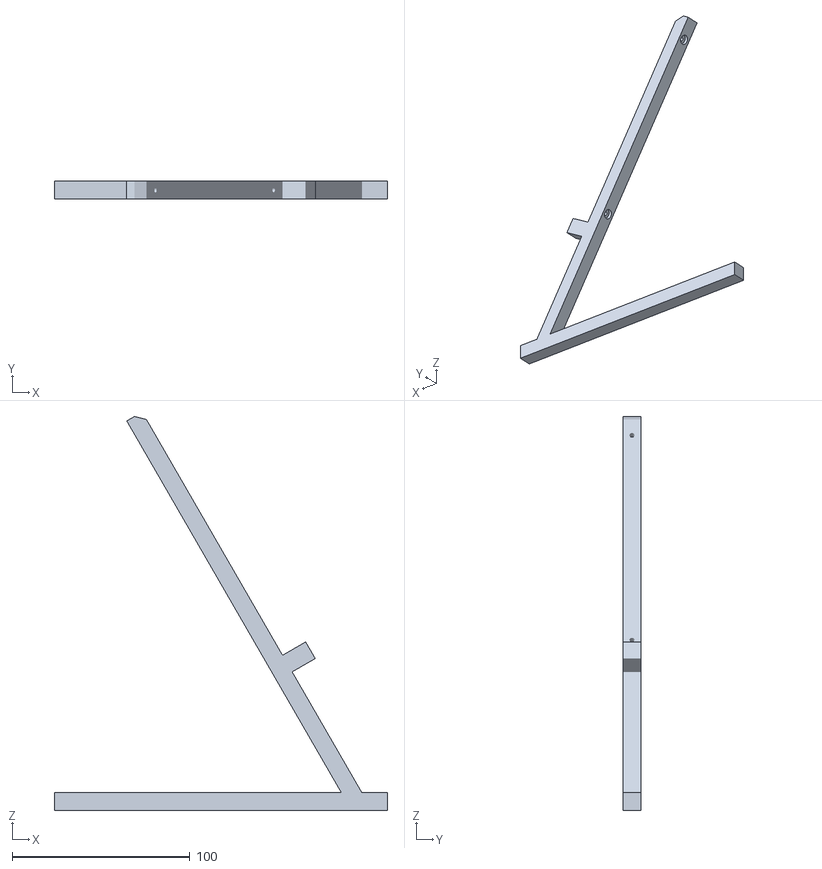
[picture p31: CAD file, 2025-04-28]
models/stl/подставка_х2.stl
187.3 x 10.0 x 221.5

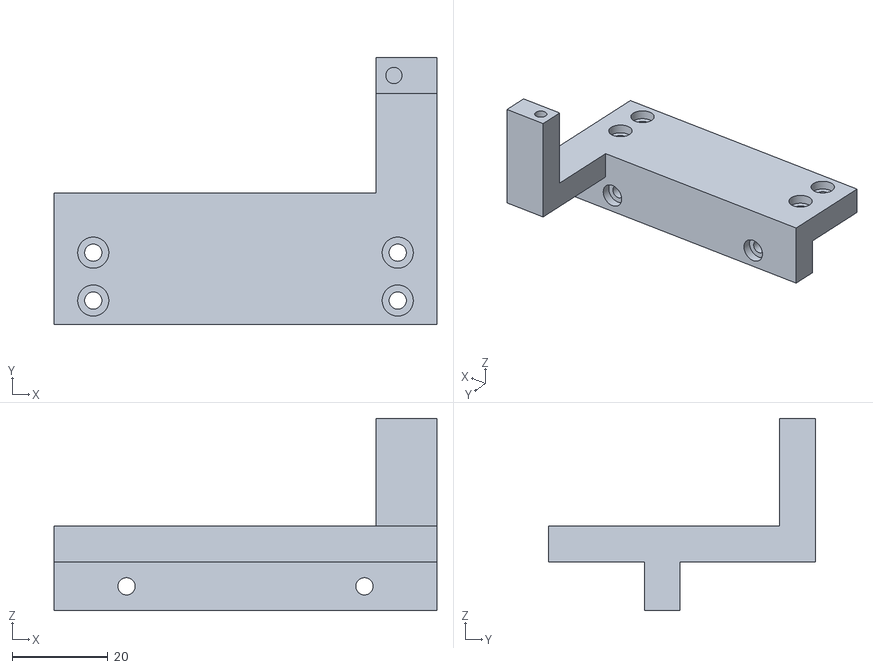
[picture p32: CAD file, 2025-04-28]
models/stl/плашках_с_крепением_тип2_х1.stl
80.0 x 55.8 x 40.2

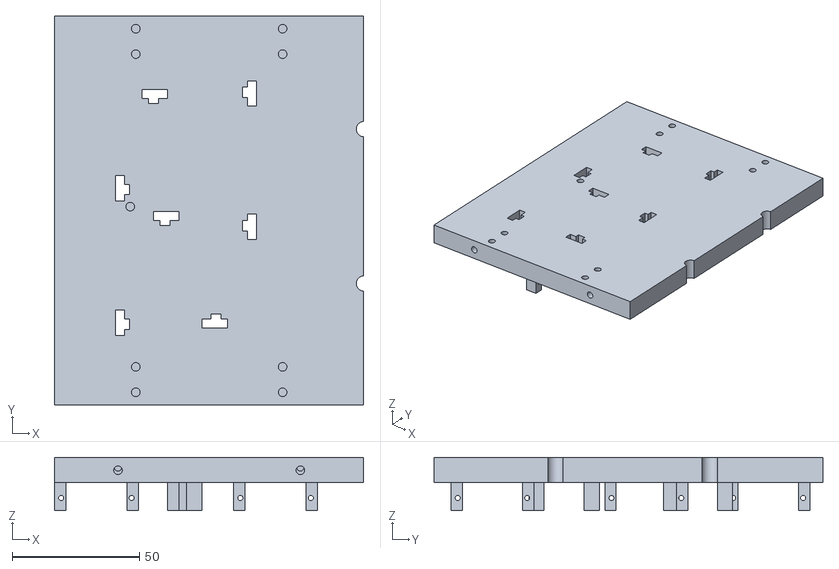
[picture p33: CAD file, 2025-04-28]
models/stl/Корпус_часть_2.stl
121.6 x 153.0 x 21.0

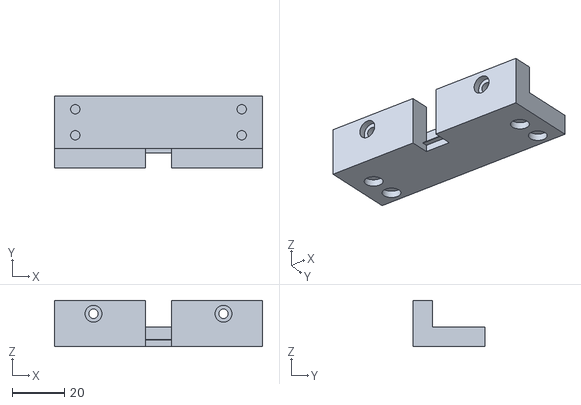
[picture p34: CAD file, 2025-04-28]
models/stl/плашкаверх_х1.stl
80.0 x 27.5 x 17.7

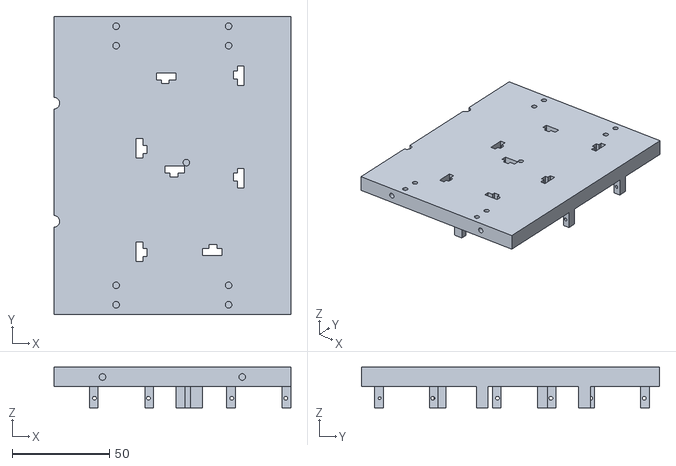
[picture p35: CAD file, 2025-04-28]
models/stl/Корпус_часть_3.stl
121.6 x 153.0 x 21.0

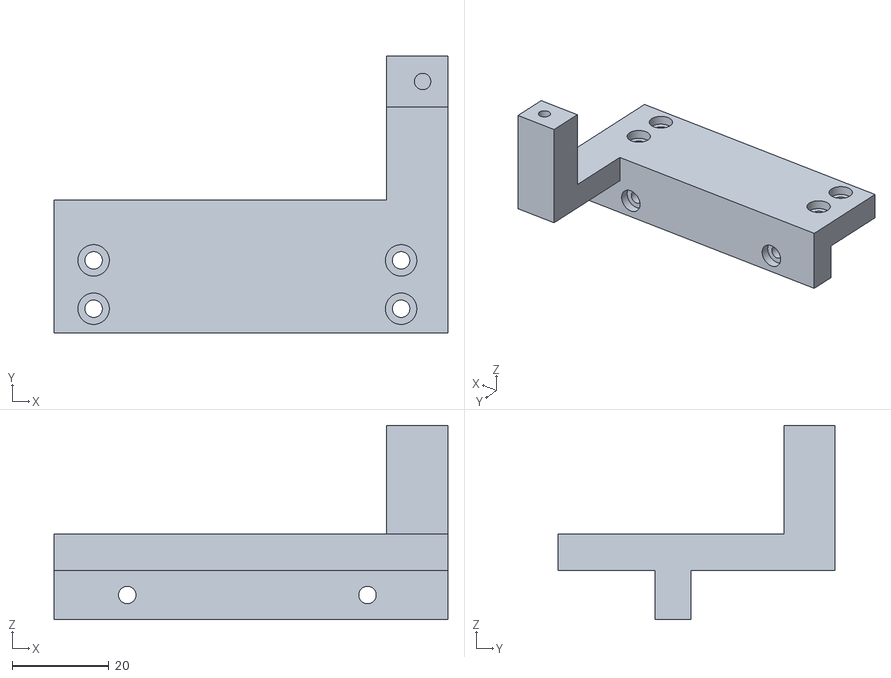
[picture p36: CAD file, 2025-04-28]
models/stl/плашках_с_креплением_х1.stl
81.5 x 57.2 x 40.2

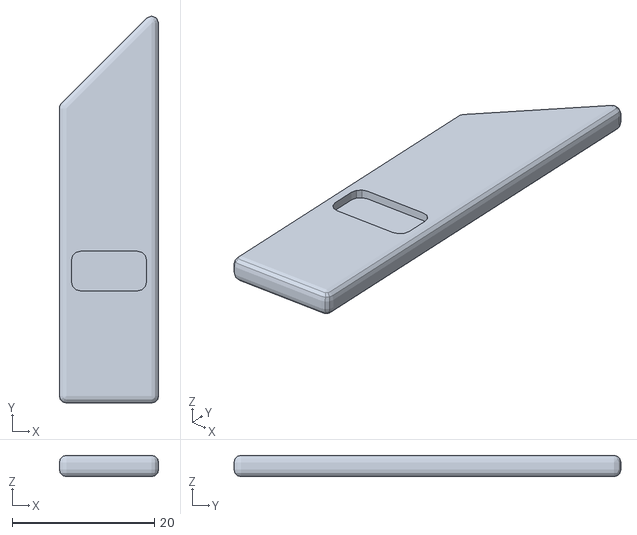
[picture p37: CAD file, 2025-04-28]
models/stl/сегмент2_х8.stl
14.0 x 54.5 x 3.00

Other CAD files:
models/stl/Корпус_часть_4.stl

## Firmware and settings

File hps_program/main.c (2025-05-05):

#include <stdio.h>
#include <stdlib.h>
#include <time.h>
#include <unistd.h>
#include <fcntl.h>
#include <sys/mman.h>
#include <string.h>
#include <arpa/inet.h>
#include <netdb.h>
#include "hwlib.h"
#include "soc_cv_av/socal/socal.h"
#include "soc_cv_av/socal/hps.h"
#include "soc_cv_av/socal/alt_gpio.h"
#include "hps_0.h"

// Константы для работы с FPGA
#define HW_REGS_BASE ( ALT_STM_OFST )
#define HW_REGS_SPAN ( 0x04000000 )
#define HW_REGS_MASK ( HW_REGS_SPAN - 1 )


void print_binary(uint32_t num) {
    for (int i = 31; i >= 0; i--) { // Перебираем биты от старшего к младшему (32 бита)
        printf("%d", (num >> i) & 1); // Выводим конкретный бит
        if (i % 4 == 0) printf(" ");  // Разделяем по 4 бита для читаемости
    }
    printf("\n");
}

int main() {
    void *virtual_base;
    int fd;
    void *h2p_lw_time_addr;
    printf("1111111");

    
    // Открытие /dev/mem для доступа к памяти
    if ((fd = open("/dev/mem", (O_RDWR | O_SYNC))) == -1) {
        printf("ERROR: could not open \"/dev/mem\"...\n");
        return 1;
    }

    printf("222222");

    // Маппинг памяти FPGA в пользовательское пространство
    virtual_base = mmap(NULL, HW_REGS_SPAN, (PROT_READ | PROT_WRITE), MAP_SHARED, fd, HW_REGS_BASE);
    if (virtual_base == MAP_FAILED) {
        printf("ERROR: mmap() failed...\n");
        close(fd);
        return 1;
    }

    printf("333333");

    // Адрес для записи времени в FPGA (замените на актуальный)
    h2p_lw_time_addr = virtual_base + ((unsigned long)(ALT_LWFPGASLVS_OFST + PIO_LED_BASE) & (unsigned long)(HW_REGS_MASK));

    printf("4444444");

    while (1) {

        int value;
        FILE *file = fopen("message_value.txt", "r");
    
        if (file == NULL) {
            perror("Error opening file");
            return 1;
        }

        fscanf(file, "%d", &value);
        fclose(file);

        printf("6666666");
        // Переменные для хранения времени
        time_t raw_time;
        struct tm *time_info;

        printf("555555");

        // Получаем текущее время
        time(&raw_time);
        time_info = localtime(&raw_time);

        printf("777777");

        // Извлекаем часы и минуты
        int hours = (time_info->tm_hour);
        int minutes = time_info->tm_min;

        printf("8888888");

        // Разделяем часы и минуты на цифры:
        uint32_t tens_hours = hours / 10;  // Десятки часов
        uint32_t ones_hours = hours % 10;  // Единицы часов
        uint32_t tens_minutes = minutes / 10;  // Десятки минут
        uint32_t ones_minutes = minutes % 10;  // Единицы минут
        uint32_t collor = value;

        printf("99999999");

        // Формируем 4 цифры для записи в FPGA
        uint32_t time_digits = ((uint32_t)collor << 16) | ((uint32_t)tens_hours << 12) | ((uint32_t)ones_hours << 8) | ((uint32_t)tens_minutes << 4) | (uint32_t)ones_minutes;

        printf("101010010101");

        // Записываем время в память FPGA (в 32-битном формате)
        *(uint32_t *)h2p_lw_time_addr = time_digits;
        printf("Time written to FPGA: %02d:%02d\n", hours, minutes); // Печать записанных цифр
        printf("binary : ");
        print_binary(time_digits);

        // Задержка между обновлениями (например, 1 секунда)
        sleep(1);
    }

    // Очистка ресурсов
    if (munmap(virtual_base, HW_REGS_SPAN) != 0) {
        printf("ERROR: munmap() failed...\n");
        close(fd);
        return 1;
    }

    close(fd);
    return 0;
}

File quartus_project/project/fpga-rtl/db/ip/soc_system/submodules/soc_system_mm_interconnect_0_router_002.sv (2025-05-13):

// (C) 2001-2017 Intel Corporation. All rights reserved.
// Your use of Intel Corporation's design tools, logic functions and other 
// software and tools, and its AMPP partner logic functions, and any output 
// files from any of the foregoing (including device programming or simulation 
// files), and any associated documentation or information are expressly subject 
// to the terms and conditions of the Intel Program License Subscription 
// Agreement, Intel FPGA IP License Agreement, or other applicable 
// license agreement, including, without limitation, that your use is for the 
// sole purpose of programming logic devices manufactured by Intel and sold by 
// Intel or its authorized distributors.  Please refer to the applicable 
// agreement for further details.



// Your use of Altera Corporation's design tools, logic functions and other 
// software and tools, and its AMPP partner logic functions, and any output 
// files any of the foregoing (including device programming or simulation 
// files), and any associated documentation or information are expressly subject 
// to the terms and conditions of the Altera Program License Subscription 
// Agreement, Altera MegaCore Function License Agreement, or other applicable 
// license agreement, including, without limitation, that your use is for the 
// sole purpose of programming logic devices manufactured by Altera and sold by 
// Altera or its authorized distributors.  Please refer to the applicable 
// agreement for further details.


// $Id: //acds/rel/17.1std/ip/merlin/altera_merlin_router/altera_merlin_router.sv.terp#1 $
// $Revision: #1 $
// $Date: 2017/07/30 $
// $Author: swbranch $

// -------------------------------------------------------
// Merlin Router
//
// Asserts the appropriate one-hot encoded channel based on 
// either (a) the address or (b) the dest id. The DECODER_TYPE
// parameter controls this behaviour. 0 means address decoder,
// 1 means dest id decoder.
//
// In the case of (a), it also sets the destination id.
// -------------------------------------------------------

`timescale 1 ns / 1 ns

module soc_system_mm_interconnect_0_router_002_default_decode
  #(
     parameter DEFAULT_CHANNEL = 0,
               DEFAULT_WR_CHANNEL = -1,
               DEFAULT_RD_CHANNEL = -1,
               DEFAULT_DESTID = 2 
   )
  (output [104 - 102 : 0] default_destination_id,
   output [5-1 : 0] default_wr_channel,
   output [5-1 : 0] default_rd_channel,
   output [5-1 : 0] default_src_channel
  );

  assign default_destination_id = 
    DEFAULT_DESTID[104 - 102 : 0];

  generate
    if (DEFAULT_CHANNEL == -1) begin : no_default_channel_assignment
      assign default_src_channel = '0;
    end
    else begin : default_channel_assignment
      assign default_src_channel = 5'b1 << DEFAULT_CHANNEL;
    end
  endgenerate

  generate
    if (DEFAULT_RD_CHANNEL == -1) begin : no_default_rw_channel_assignment
      assign default_wr_channel = '0;
      assign default_rd_channel = '0;
    end
    else begin : default_rw_channel_assignment
      assign default_wr_channel = 5'b1 << DEFAULT_WR_CHANNEL;
      assign default_rd_channel = 5'b1 << DEFAULT_RD_CHANNEL;
    end
  endgenerate

endmodule


module soc_system_mm_interconnect_0_router_002
(
    // -------------------
    // Clock & Reset
    // -------------------
    input clk,
    input reset,

    // -------------------
    // Command Sink (Input)
    // -------------------
    input                       sink_valid,
    input  [129-1 : 0]    sink_data,
    input                       sink_startofpacket,
    input                       sink_endofpacket,
    output                      sink_ready,

    // -------------------
    // Command Source (Output)
    // -------------------
    output                          src_valid,
    output reg [129-1    : 0] src_data,
    output reg [5-1 : 0] src_channel,
    output                          src_startofpacket,
    output                          src_endofpacket,
    input                           src_ready
);

    // -------------------------------------------------------
    // Local parameters and variables
    // -------------------------------------------------------
    localparam PKT_ADDR_H = 67;
    localparam PKT_ADDR_L = 36;
    localparam PKT_DEST_ID_H = 104;
    localparam PKT_DEST_ID_L = 102;
    localparam PKT_PROTECTION_H = 119;
    localparam PKT_PROTECTION_L = 117;
    localparam ST_DATA_W = 129;
    localparam ST_CHANNEL_W = 5;
    localparam DECODER_TYPE = 0;

    localparam PKT_TRANS_WRITE = 70;
    localparam PKT_TRANS_READ  = 71;

    localparam PKT_ADDR_W = PKT_ADDR_H-PKT_ADDR_L + 1;
    localparam PKT_DEST_ID_W = PKT_DEST_ID_H-PKT_DEST_ID_L + 1;



    // -------------------------------------------------------
    // Figure out the number of bits to mask off for each slave span
    // during address decoding
    // -------------------------------------------------------
    localparam PAD0 = log2ceil(64'h10000 - 64'h0); 
    localparam PAD1 = log2ceil(64'h10008 - 64'h10000); 
    localparam PAD2 = log2ceil(64'h20008 - 64'h20000); 
    localparam PAD3 = log2ceil(64'h30008 - 64'h30000); 
    // -------------------------------------------------------
    // Work out which address bits are significant based on the
    // address range of the slaves. If the required width is too
    // large or too small, we use the address field width instead.
    // -------------------------------------------------------
    localparam ADDR_RANGE = 64'h30008;
    localparam RANGE_ADDR_WIDTH = log2ceil(ADDR_RANGE);
    localparam OPTIMIZED_ADDR_H = (RANGE_ADDR_WIDTH > PKT_ADDR_W) ||
                                  (RANGE_ADDR_WIDTH == 0) ?
                                        PKT_ADDR_H :
                                        PKT_ADDR_L + RANGE_ADDR_WIDTH - 1;

    localparam RG = RANGE_ADDR_WIDTH-1;
    localparam REAL_ADDRESS_RANGE = OPTIMIZED_ADDR_H - PKT_ADDR_L;

      reg [PKT_ADDR_W-1 : 0] address;
      always @* begin
        address = {PKT_ADDR_W{1'b0}};
        address [REAL_ADDRESS_RANGE:0] = sink_data[OPTIMIZED_ADDR_H : PKT_ADDR_L];
      end   

    // -------------------------------------------------------
    // Pass almost everything through, untouched
    // -------------------------------------------------------
    assign sink_ready        = src_ready;
    assign src_valid         = sink_valid;
    assign src_startofpacket = sink_startofpacket;
    assign src_endofpacket   = sink_endofpacket;
    wire [PKT_DEST_ID_W-1:0] default_destid;
    wire [5-1 : 0] default_src_channel;




    // -------------------------------------------------------
    // Write and read transaction signals
    // -------------------------------------------------------
    wire read_transaction;
    assign read_transaction  = sink_data[PKT_TRANS_READ];
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

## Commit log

2025-04-08 Добавлены файлы HPS
2025-04-08 Добавлены тестбенчи и питон программа
2025-04-28 add models
    [Корпус_часть_2.stl, Корпус_часть_3.stl, Корпус_часть_4.stl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]
